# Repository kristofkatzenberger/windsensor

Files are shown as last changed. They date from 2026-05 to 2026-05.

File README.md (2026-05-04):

# Portable Wind Sensor based on MEMS Pressure Sensors

This repository contains the design files for a portable wind sensor developed in 2025/26 at the University of Applied Sciences Technikum Wien. This project was completed as part of the Bachelor's Thesis:

"Entwicklung eines tragbaren Windsensors auf Basis von MEMS-Drucksensoren"
(Development of a Portable Wind Sensor Based on MEMS Pressure Sensors)

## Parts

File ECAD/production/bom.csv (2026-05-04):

Designator | Footprint | Quantity | Value | LCSC Part #
C1, C12, C4, C7, C9 | 0402 | 5 | 10uF
C10 | 0402 | 1 | 47nF
C11, C19, C2, C21, C22, C23, C24, C25, C26, C27, C28, C29, C30, C31, C32, C33, C34, C35, C36, C37, C38, C39, C40, C41, C43, C44, C45, C47, C5, C6 | 0402 | 30 | 100nF
C13 | 0402 | 1 | 4.7uF
C14 | 0402 | 1 | 20uF
C15, C16, C17, C20, C3, C46 | 0402 | 6 | 1uF
C18, C8 | 0402 | 2 | 22uF
C42 | 0402 | 1 | 2.2uF
D1 | 0603 | 1 | LED WHITE
D2 | 0603 | 1 | LED RED
D3, D4 | LESD5D50CT1G | 2 | LESD5D5.0CT1G
IC1 | AP33772SDKZ13FA01 | 1 | AP33772SDKZ-13-FA01
IC2 | SON65P200X200X80-7N | 1 | LP5910-1.8DRVR
IC3 | BMI270 | 1 | BMI270
J1 | USB_C_Receptacle_GCT_USB4105-xx-A_16P_TopMnt_Horizontal | 1 | USB_C_Receptacle_USB2.0_16P
J3 | JST_ZH_B2B-ZR-SM4-TF_1x02-1MP_P1.50mm_Vertical | 1 | Conn_01x02_Pin
J7 | JST_SM13B-GHS-TB | 1 | SM13B-GHS-TB
L1 | L_Murata_DFE201610P | 1 | 470nH
L2 | 1008 | 1 | 1uH
Q1, Q2 | Diodes_PowerDI3333-8 | 2 | DMN3008SFG
R1 | 0402 | 1 | 6,2k
R10, R17, R32, R39, R40, R41, R42, R43, R44, R6, R7 | 0402 | 11 | 10k
R11 | 0402 | 1 | 511k
R12 | 0402 | 1 | 1.5k
R14 | 0402 | 1 | 91k
R15, R16, R22, R23, R24, R25, R26, R27, R28, R29, R30, R31 | 0402 | 12 | 4.7k
R18, R19, R20, R21 | 0402 | 4 | 100k
R2 | 0402 | 1 | 100
R3 | 1206 | 1 | 5m
R33, R34, R35, R36, R37, R38 | 0402 | 6 | 50
R4, R5 | 0402 | 2 | 5.1k
R8 | 0402 | 1 | 30.1k
R9 | 0402 | 1 | 5.23k
TF1 | TF-SMD_TF-012 | 1 | TF-012
TH1 | 0603 | 1 | SDNT1608X103F3950FTF
U1 | WQFN-HR18__RYK_TEX | 1 | BQ25628ERYKR
U10, U11, U12, U4, U5, U6, U7, U8, U9 | LGA8S145X65P2X4_200X250X110-V | 9 | DPS368
U13 | BGA9_BMM350_BOS | 1 | BMM350
U14 | TSSOP-24_4.4x7.8mm_P0.65mm | 1 | TCA9548APWR
U2 | YFF0015AHAN | 1 | TPS63805YFFR
U3 | ESP32-S3-WROOM-1 | 1 | ESP32-S3-WROOM-1

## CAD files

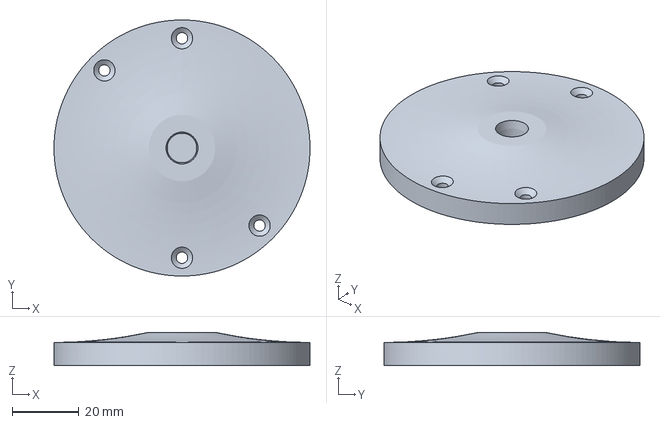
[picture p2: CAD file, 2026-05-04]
MCAD/WindSensor-Tripod-Adapter.3mf
77.0 x 77.0 x 10.0 mm

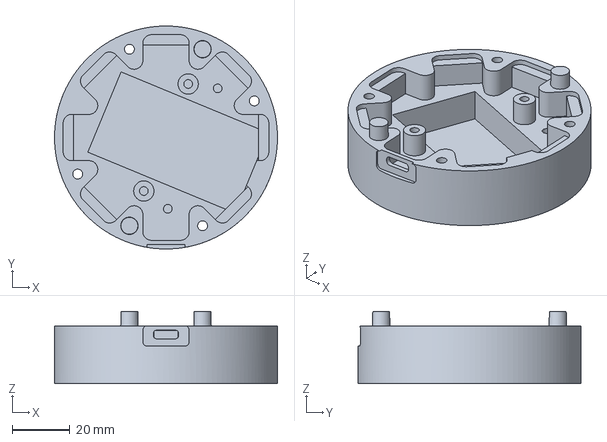
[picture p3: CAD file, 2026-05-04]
MCAD/WindSensor-Bottom.3mf
77.0 x 77.0 x 25.0 mm

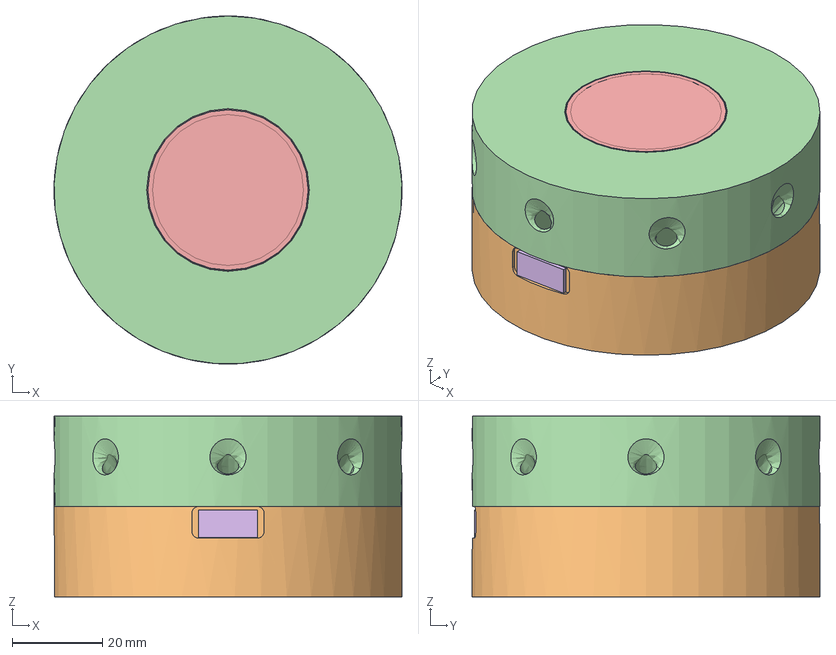
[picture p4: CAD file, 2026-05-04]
MCAD/WindSensor.FCStd
77.0 x 77.0 x 40.0 mm
M3x3.8-Insert018
M3x3.8-Insert017
M3x3.8-Insert016
M3x3.8-Insert
M3x12-Screw027
M2x6-Screw018
M2x6-Screw017
M2x6-Screw016
M2x6-Screw
M3x8-Screw018
M3x8-Screw017
M3x8-Screw016
M3x8-Screw
M3x6-Screw018
M3x6-Screw017
M3x6-Screw016
M3x6-Screw
BatteryHolder
ScreenConnector
1_28INCH-240X240-TFT
1_28INCH-240X240-TFT-TOUCH
1_28INCH_TOUCH_LCD-PCBA
1_28INCH_TOUCH_LCD-PCBA001
STUDS-M2XH2_5
STUDS-M2XH2_006
STUDS-M2XH2_007
STUDS-M2XH2_008
Top
Battery
USB-C-Plug
M3x12-Screw028
M3x12-Screw029
M3x12-Screw030
Bottom
PCB

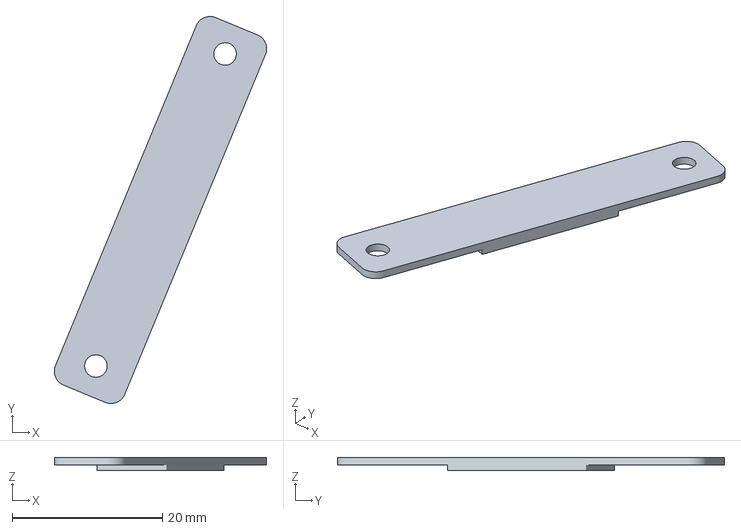
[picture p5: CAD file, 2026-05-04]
MCAD/WindSensor-BatteryHolder.3mf
28.3 x 51.6 x 1.70 mm

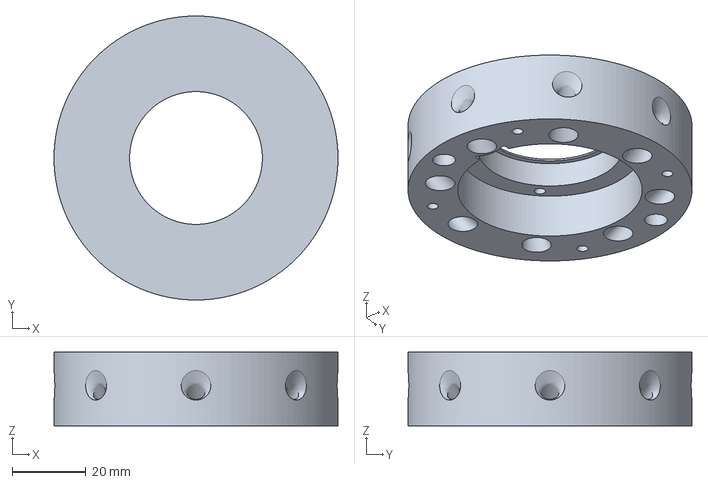
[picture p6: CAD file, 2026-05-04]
MCAD/WindSensor-Top.3mf
77.0 x 77.0 x 20.0 mm

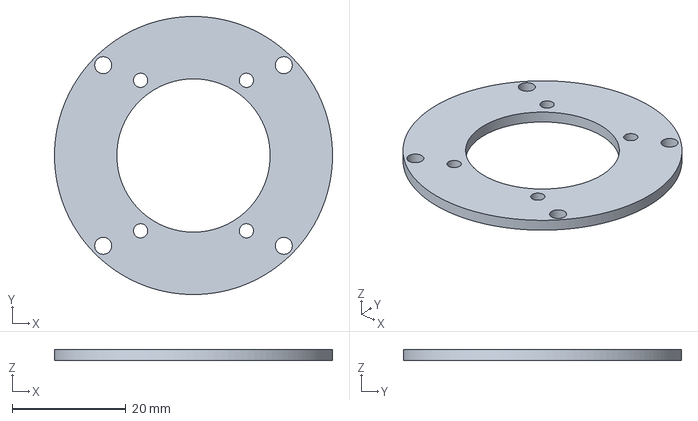
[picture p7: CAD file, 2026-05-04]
MCAD/WindSensor-ScreenConnector.3mf
49.0 x 49.0 x 2.00 mm

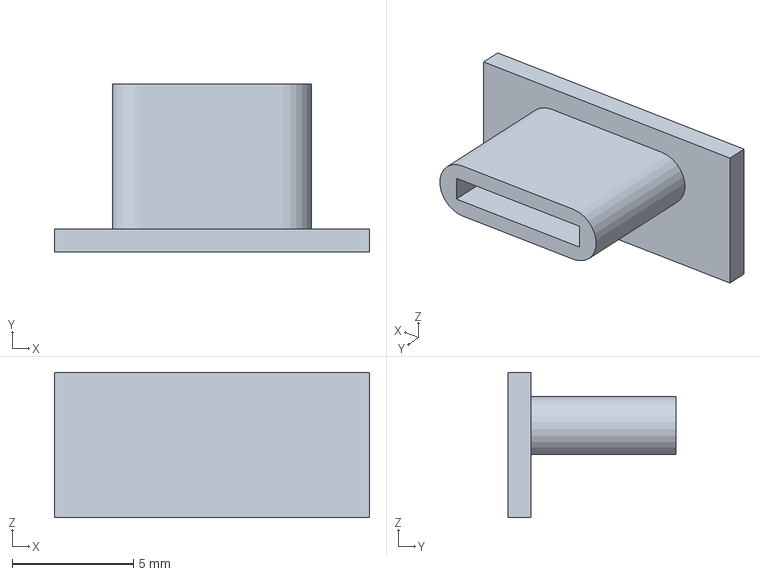
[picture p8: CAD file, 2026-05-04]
MCAD/WindSensor-USB-C-Plug.3mf
13.0 x 6.95 x 6.00 mm

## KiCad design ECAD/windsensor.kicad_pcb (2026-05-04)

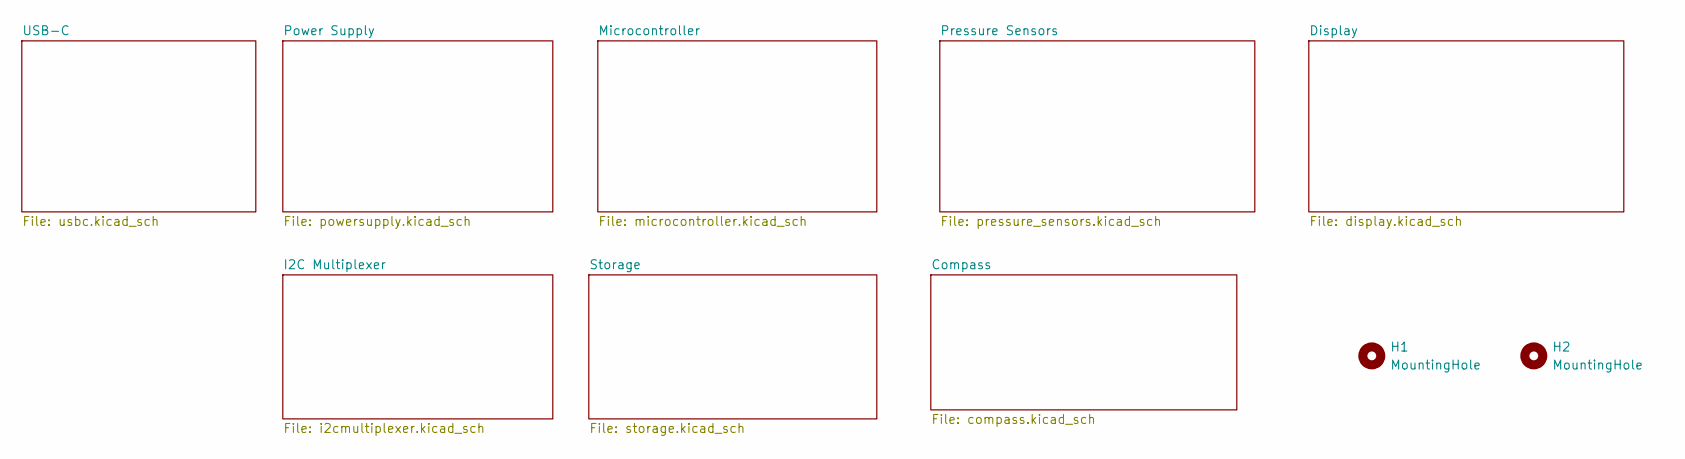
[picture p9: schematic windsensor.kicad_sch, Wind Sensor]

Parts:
H1, H2: MountingHole; MountingHole_3.2mm_M3

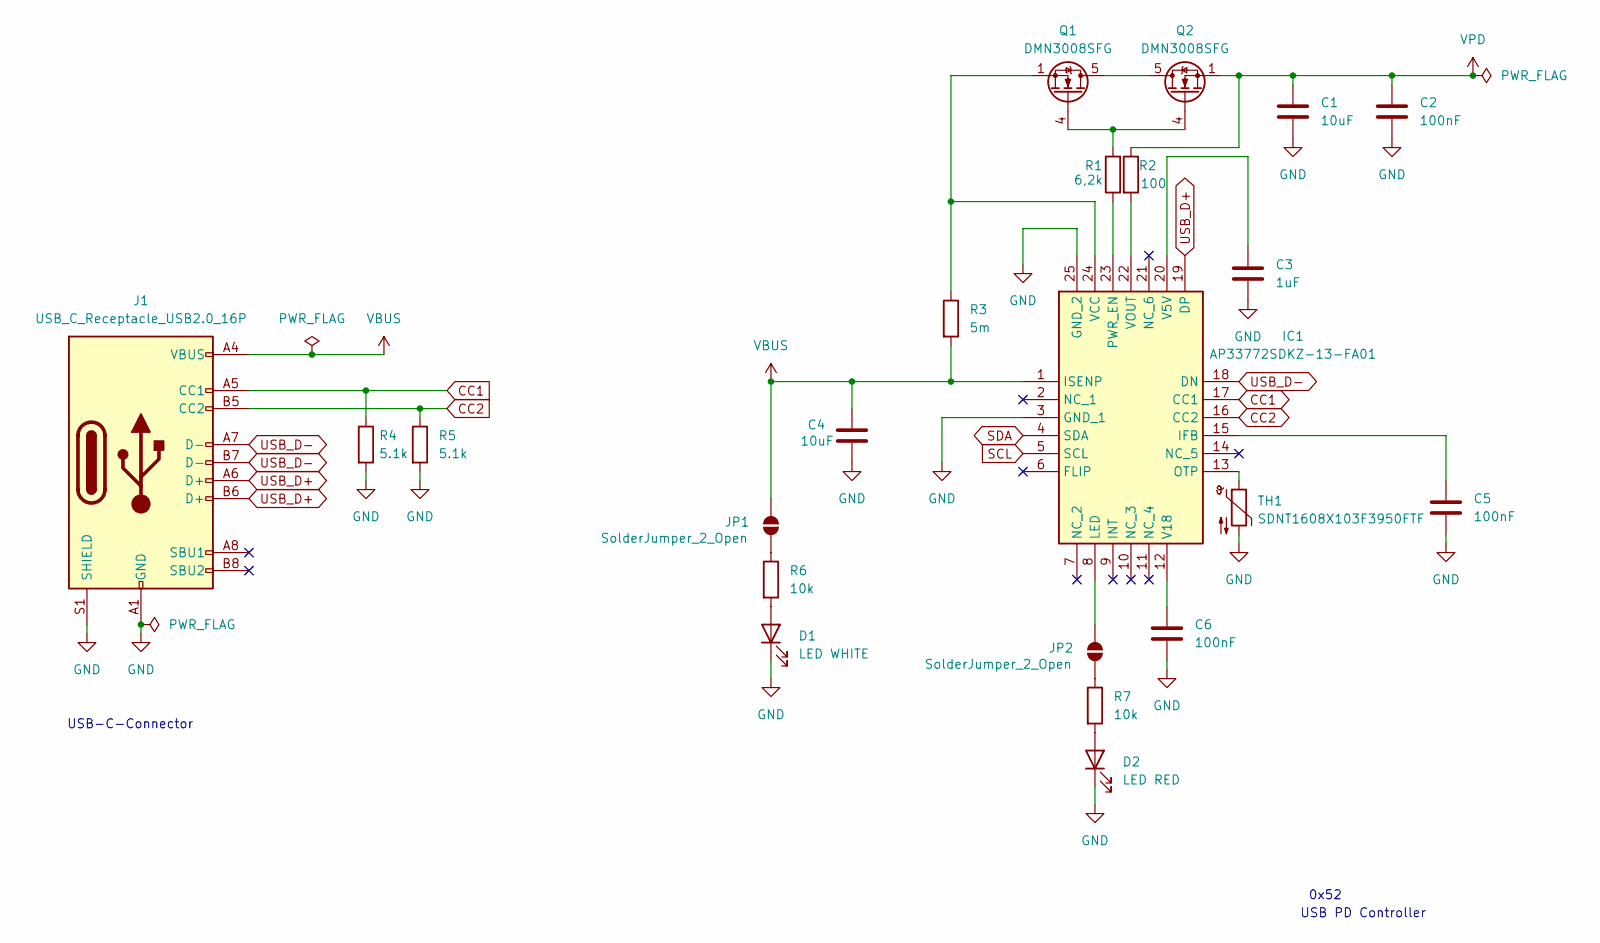
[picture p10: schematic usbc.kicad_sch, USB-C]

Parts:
C1, C4: 10uF; C_0402_1005Metric
C2, C5, C6: 100nF; C_0402_1005Metric
C3: 1uF; C_0402_1005Metric
D1: LED WHITE; LED_0603_1608Metric
D2: LED RED; LED_0603_1608Metric
IC1: AP33772SDKZ-13-FA01; AP33772SDKZ13FA01; Manufacturer_Part_Number AP33772SDKZ-13-FA01; Mouser Part Number 621-P33772SDKZ13FA01
J1: USB_C_Receptacle_USB2.0_16P; USB_C_Receptacle_GCT_USB4105-xx-A_16P_TopMnt_Horizontal
JP1, JP2: SolderJumper_2_Open; SolderJumper-2_P1.3mm_Open_TrianglePad1.0x1.5mm
Q1, Q2: DMN3008SFG; Diodes_PowerDI3333-8
R1: 6,2k; R_0402_1005Metric
R2: 100; R_0402_1005Metric
R3: 5m; R_1206_3216Metric; Tolerance 1%
R4, R5: 5.1k; R_0402_1005Metric
R6, R7: 10k; R_0402_1005Metric
TH1: SDNT1608X103F3950FTF; R_0603_1608Metric

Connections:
CC1: IC1.17 (CC1), J1.A5 (CC1), R4.1
CC2: IC1.16 (CC2), J1.B5 (CC2), R5.1
GND: C1.2, C2.2, C3.2, C4.2, C5.2, C6.2, D1.1 (K), D2.1 (K), IC1.3 (GND_1), IC1.25 (GND_2), J1.A1 (GND), J1.A12 (GND), J1.B1 (GND), J1.B12 (GND), J1.S1 (SHIELD), R4.2, R5.2, TH1.2; also elsewhere on the board
unnamed: D1.2 (A), R6.2
unnamed: D2.2 (A), R7.2
unnamed: C5.1, IC1.15 (IFB)
unnamed: IC1.8 (LED), JP2.1 (A)
unnamed: IC1.13 (OTP), TH1.1
unnamed: IC1.23 (PWR_EN), R1.1
unnamed: C3.1, IC1.20 (V5V)
unnamed: C6.1, IC1.12 (V18)
unnamed: IC1.24 (VCC), Q1.1 (S), Q1.2 (S), Q1.3 (S), R3.1
unnamed: IC1.22 (VOUT), R2.2
unnamed: JP1.2 (B), R6.1
unnamed: JP2.2 (B), R7.1
unnamed: Q1.5 (D), Q2.5 (D)
unnamed: Q1.4 (G), Q2.4 (G), R1.2
SCL: IC1.5 (SCL); also elsewhere on the board
SDA: IC1.4 (SDA); also elsewhere on the board
USB_D+: IC1.19 (DP), J1.A6 (D+), J1.B6 (D+); also elsewhere on the board
USB_D-: IC1.18 (DN), J1.A7 (D-), J1.B7 (D-); also elsewhere on the board
VBUS: C4.1, IC1.1 (ISENP), J1.A4 (VBUS), J1.A9 (VBUS), J1.B4 (VBUS), J1.B9 (VBUS), JP1.1 (A), R3.2
VPD: C1.1, C2.1, Q2.1 (S), Q2.2 (S), Q2.3 (S), R2.1; also elsewhere on the board

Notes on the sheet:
USB PD Controller
USB-C-Connector
0x52

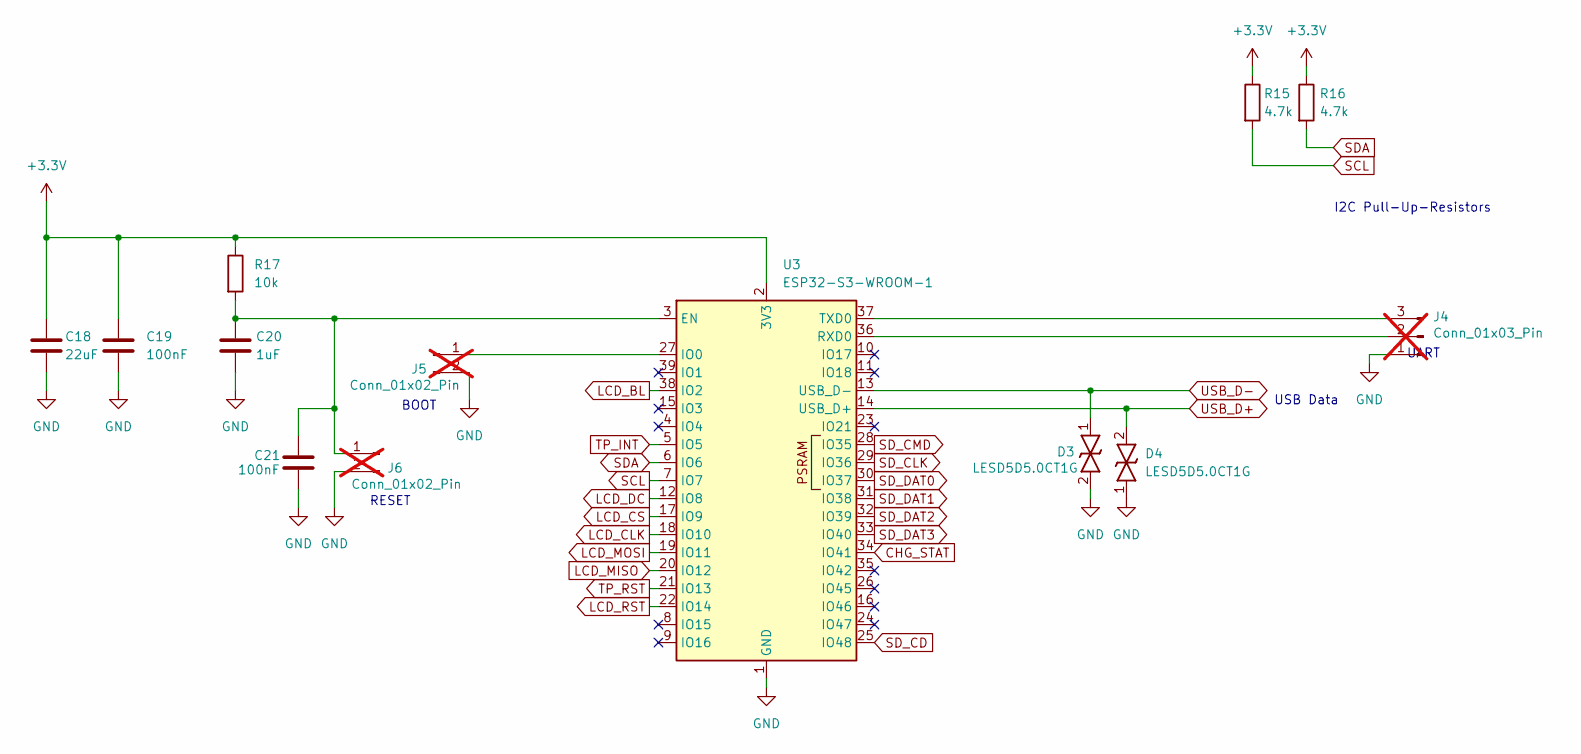
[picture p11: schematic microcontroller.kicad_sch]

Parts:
C18: 22uF; C_0402_1005Metric
C19, C21: 100nF; C_0402_1005Metric
C20: 1uF; C_0402_1005Metric
D3, D4: LESD5D5.0CT1G; LESD5D50CT1G; Manufacturer_Part_Number LESD5D5.0CT1G
J4: Conn_01x03_Pin; PinHeader_1x03_P2.54mm_Vertical; not fitted
J5, J6: Conn_01x02_Pin; PinHeader_1x02_P2.54mm_Vertical; not fitted
R15, R16: 4.7k; R_0402_1005Metric
R17: 10k; R_0402_1005Metric
U3: ESP32-S3-WROOM-1

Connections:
+3.3V: C18.1, C19.1, R15.1, R16.1, R17.1, U3.2 (3V3); also elsewhere on the board
CHG_STAT: U3.34 (IO41); also elsewhere on the board
GND: C18.2, C19.2, C20.2, C21.2, D3.2, D4.1, J4.1, J5.2, J6.2, U3.1 (GND), U3.40 (GND), U3.41 (GND); also elsewhere on the board
LCD_BL: U3.38 (IO2); also elsewhere on the board
LCD_CLK: U3.18 (IO10); also elsewhere on the board
LCD_CS: U3.17 (IO9); also elsewhere on the board
LCD_DC: U3.12 (IO8); also elsewhere on the board
LCD_MISO: U3.20 (IO12); also elsewhere on the board
LCD_MOSI: U3.19 (IO11); also elsewhere on the board
LCD_RST: U3.22 (IO14); also elsewhere on the board
unnamed: J4.2, U3.36 (RXD0)
unnamed: J4.3, U3.37 (TXD0)
unnamed: J5.1, U3.27 (IO0)
unnamed: C20.1, C21.1, J6.1, R17.2, U3.3 (EN)
SCL: R15.2, U3.7 (IO7); also elsewhere on the board
SDA: R16.2, U3.6 (IO6); also elsewhere on the board
SD_CD: U3.25 (IO48); also elsewhere on the board
SD_CLK: U3.29 (IO36); also elsewhere on the board
SD_CMD: U3.28 (IO35); also elsewhere on the board
SD_DAT0: U3.30 (IO37); also elsewhere on the board
SD_DAT1: U3.31 (IO38); also elsewhere on the board
SD_DAT2: U3.32 (IO39); also elsewhere on the board
SD_DAT3: U3.33 (IO40); also elsewhere on the board
TP_INT: U3.5 (IO5); also elsewhere on the board
TP_RST: U3.21 (IO13); also elsewhere on the board
USB_D+: D4.2, U3.14 (USB_D+); also elsewhere on the board
USB_D-: D3.1, U3.13 (USB_D-); also elsewhere on the board

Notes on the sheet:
I2C Pull-Up-Resistors
UART
USB Data
BOOT
RESET

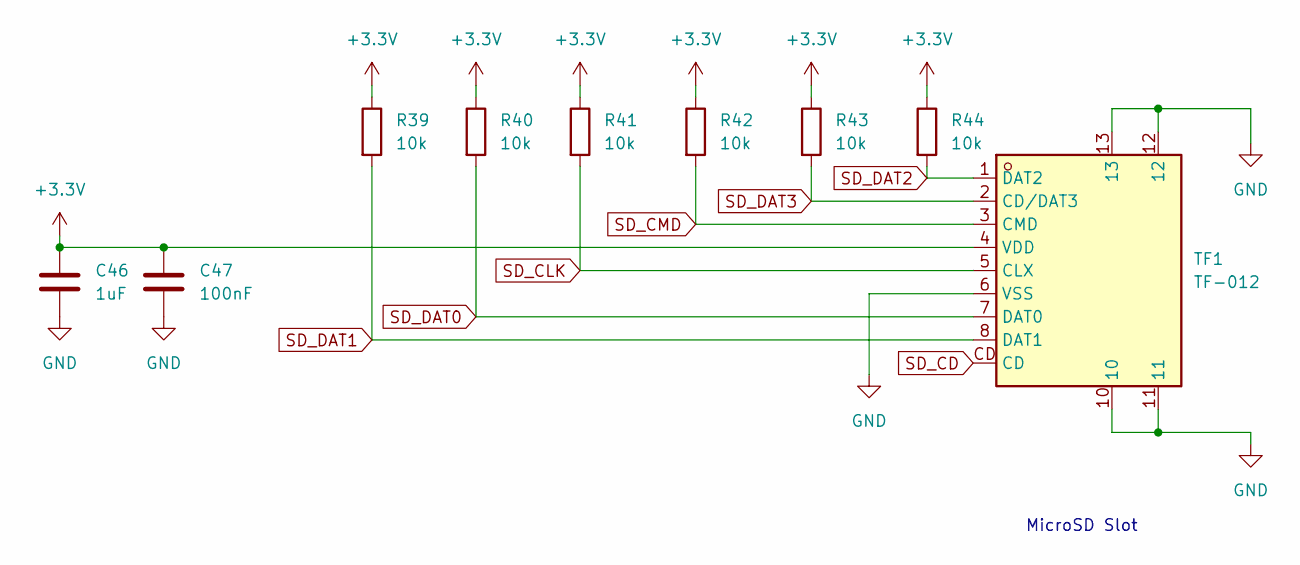
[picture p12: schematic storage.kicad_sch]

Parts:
C46: 1uF; C_0402_1005Metric
C47: 100nF; C_0402_1005Metric
R39, R40, R41, R42, R43, R44: 10k; R_0402_1005Metric
TF1: TF-012; TF-SMD_TF-012; Manufacturer Part TF-012; LCSC Part Name 自弹式 MicroSD卡(TF卡) 卡座

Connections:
+3.3V: C46.1, C47.1, R39.1, R40.1, R41.1, R42.1, R43.1, R44.1, TF1.4 (VDD); also elsewhere on the board
GND: C46.2, C47.2, TF1.6 (VSS), TF1.10, TF1.11, TF1.12, TF1.13; also elsewhere on the board
SD_CD: TF1.CD; also elsewhere on the board
SD_CLK: R41.2, TF1.5 (CLX); also elsewhere on the board
SD_CMD: R42.2, TF1.3 (CMD); also elsewhere on the board
SD_DAT0: R40.2, TF1.7 (DAT0); also elsewhere on the board
SD_DAT1: R39.2, TF1.8 (DAT1); also elsewhere on the board
SD_DAT2: R44.2, TF1.1 (DAT2); also elsewhere on the board
SD_DAT3: R43.2, TF1.2 (CD/DAT3); also elsewhere on the board

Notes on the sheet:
MicroSD Slot

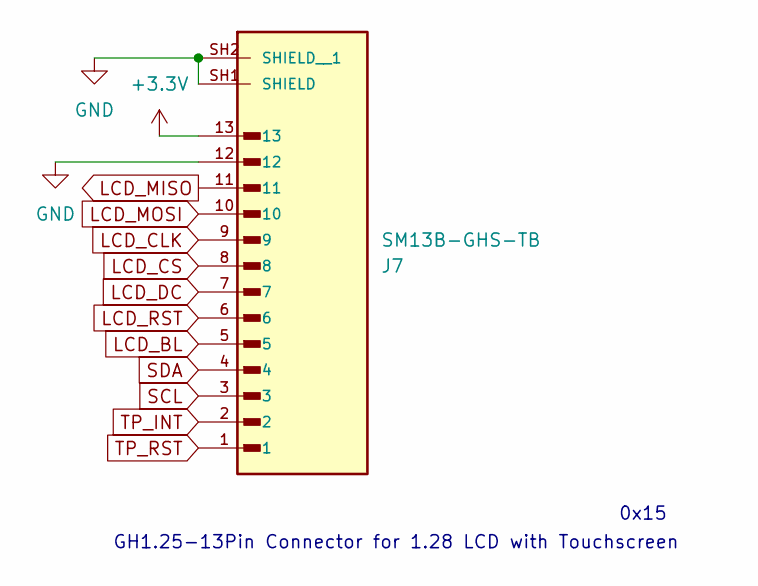
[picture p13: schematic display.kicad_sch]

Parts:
J7: SM13B-GHS-TB; JST_SM13B-GHS-TB; PARTREV 18/3/21

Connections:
+3.3V: J7.13; also elsewhere on the board
GND: J7.12, J7.SH1 (SHIELD), J7.SH2 (SHIELD__1); also elsewhere on the board
LCD_BL: J7.5; also elsewhere on the board
LCD_CLK: J7.9; also elsewhere on the board
LCD_CS: J7.8; also elsewhere on the board
LCD_DC: J7.7; also elsewhere on the board
LCD_MISO: J7.11; also elsewhere on the board
LCD_MOSI: J7.10; also elsewhere on the board
LCD_RST: J7.6; also elsewhere on the board
SCL: J7.3; also elsewhere on the board
SDA: J7.4; also elsewhere on the board
TP_INT: J7.2; also elsewhere on the board
TP_RST: J7.1; also elsewhere on the board

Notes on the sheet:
GH1.25-13Pin Connector for 1.28 LCD with Touchscreen
0x15

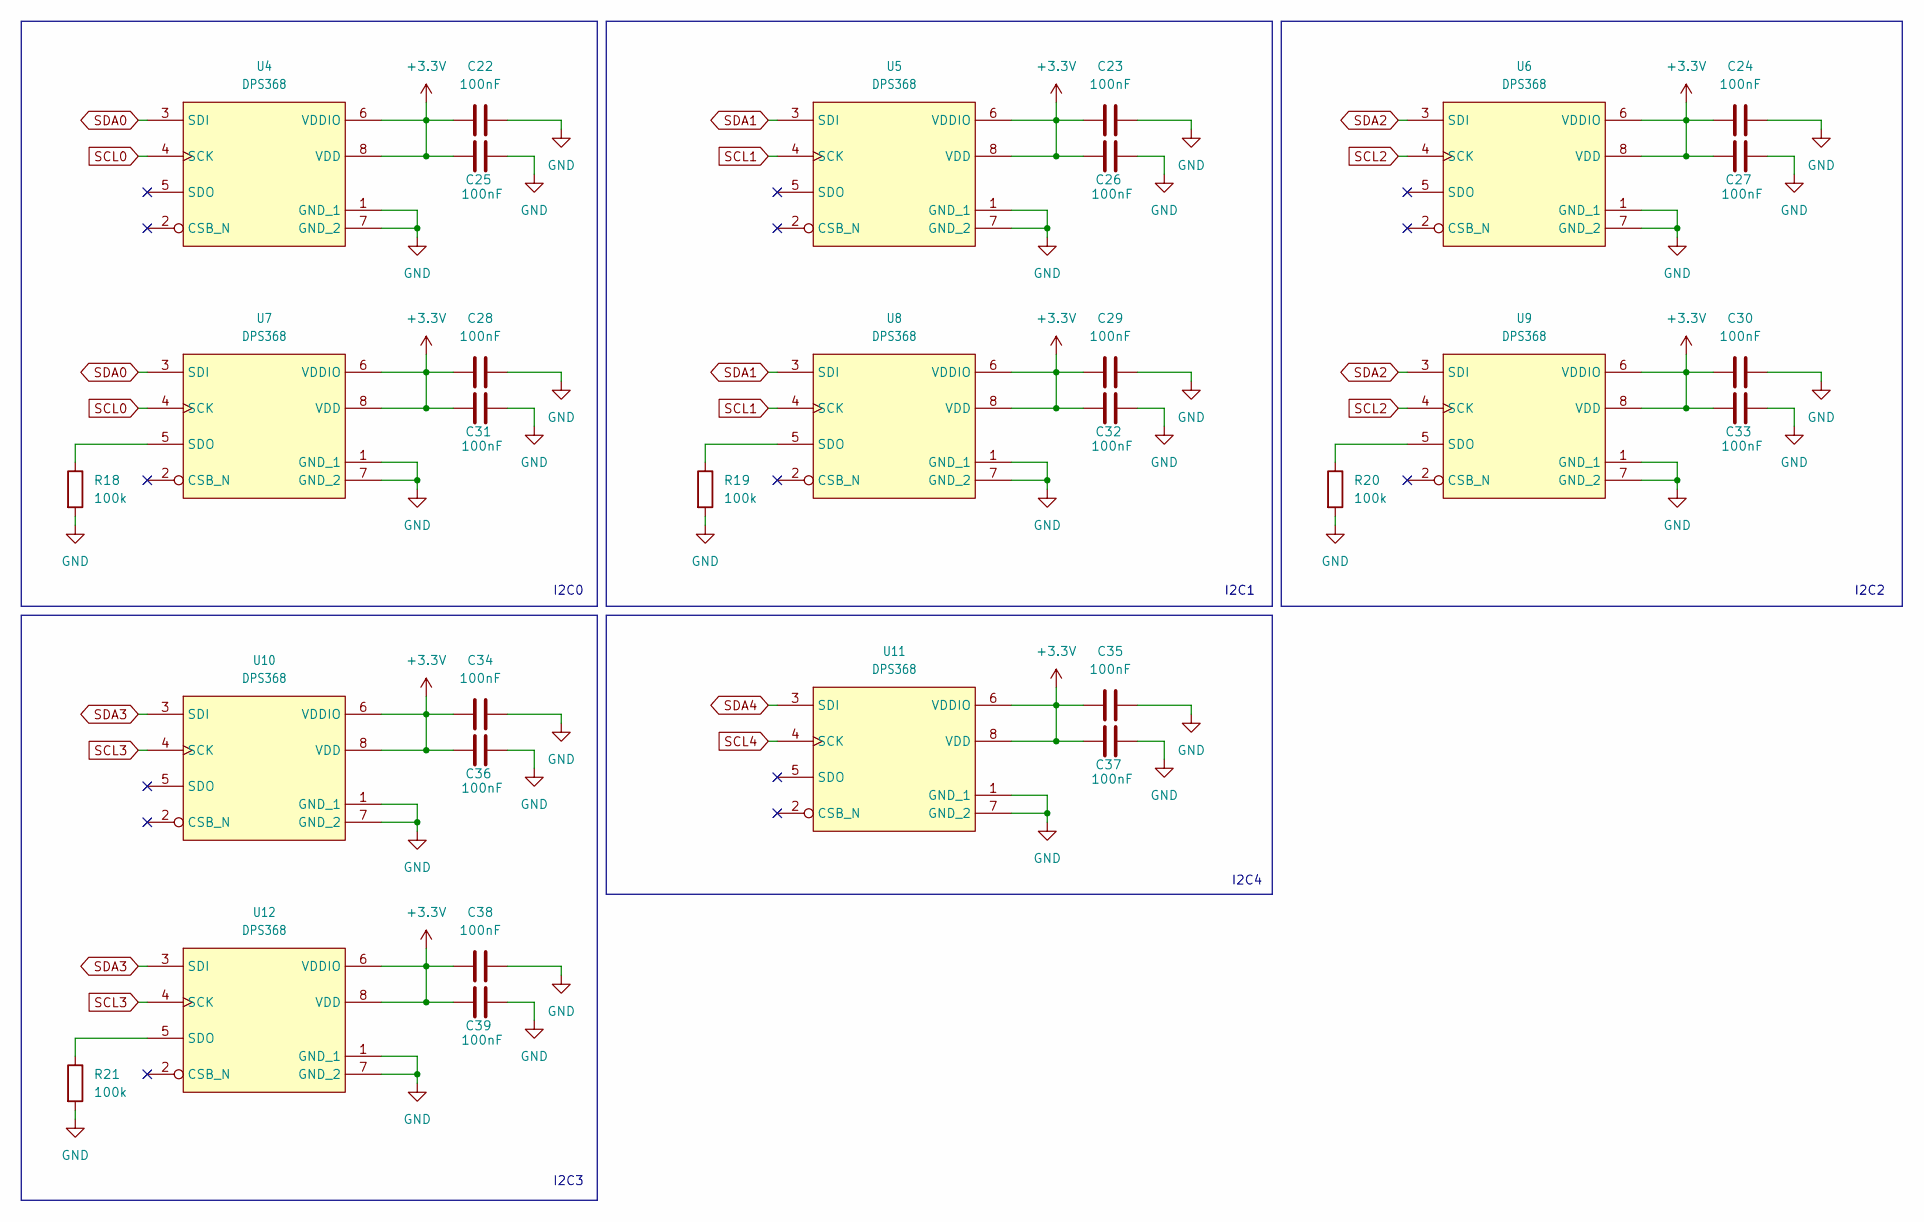
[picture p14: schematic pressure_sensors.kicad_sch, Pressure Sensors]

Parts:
C22, C23, C24, C25, C26, C27, C28, C29, C30, C31, C32, C33, C34, C35, C36, C37, C38, C39: 100nF; C_0402_1005Metric
R18, R19, R20, R21: 100k; R_0402_1005Metric
U4, U5, U6, U7, U8, U9, U10, U11, U12: DPS368; LGA8S145X65P2X4_200X250X110-V

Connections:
+3.3V: C22.1, C23.1, C24.1, C25.1, C26.1, C27.1, C28.1, C29.1, C30.1, C31.1, C32.1, C33.1, C34.1, C35.1, C36.1, C37.1, C38.1, C39.1, U4.6 (VDDIO), U4.8 (VDD), U5.6 (VDDIO), U5.8 (VDD), U6.6 (VDDIO), U6.8 (VDD), U7.6 (VDDIO), U7.8 (VDD), U8.6 (VDDIO), U8.8 (VDD), U9.6 (VDDIO), U9.8 (VDD), U10.6 (VDDIO), U10.8 (VDD), U11.6 (VDDIO), U11.8 (VDD), U12.6 (VDDIO), U12.8 (VDD); also elsewhere on the board
GND: C22.2, C23.2, C24.2, C25.2, C26.2, C27.2, C28.2, C29.2, C30.2, C31.2, C32.2, C33.2, C34.2, C35.2, C36.2, C37.2, C38.2, C39.2, R18.2, R19.2, R20.2, R21.2, U4.1 (GND_1), U4.7 (GND_2), U5.1 (GND_1), U5.7 (GND_2), U6.1 (GND_1), U6.7 (GND_2), U7.1 (GND_1), U7.7 (GND_2), U8.1 (GND_1), U8.7 (GND_2), U9.1 (GND_1), U9.7 (GND_2), U10.1 (GND_1), U10.7 (GND_2), U11.1 (GND_1), U11.7 (GND_2), U12.1 (GND_1), U12.7 (GND_2); also elsewhere on the board
unnamed: R18.1, U7.5 (SDO)
unnamed: R19.1, U8.5 (SDO)
unnamed: R20.1, U9.5 (SDO)
unnamed: R21.1, U12.5 (SDO)
SCL0: U4.4 (SCK), U7.4 (SCK); also elsewhere on the board
SCL1: U5.4 (SCK), U8.4 (SCK); also elsewhere on the board
SCL2: U6.4 (SCK), U9.4 (SCK); also elsewhere on the board
SCL3: U10.4 (SCK), U12.4 (SCK); also elsewhere on the board
SCL4: U11.4 (SCK); also elsewhere on the board
SDA0: U4.3 (SDI), U7.3 (SDI); also elsewhere on the board
SDA1: U5.3 (SDI), U8.3 (SDI); also elsewhere on the board
SDA2: U6.3 (SDI), U9.3 (SDI); also elsewhere on the board
SDA3: U10.3 (SDI), U12.3 (SDI); also elsewhere on the board
SDA4: U11.3 (SDI); also elsewhere on the board

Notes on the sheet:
I2C3
I2C2
I2C4
I2C1
I2C0

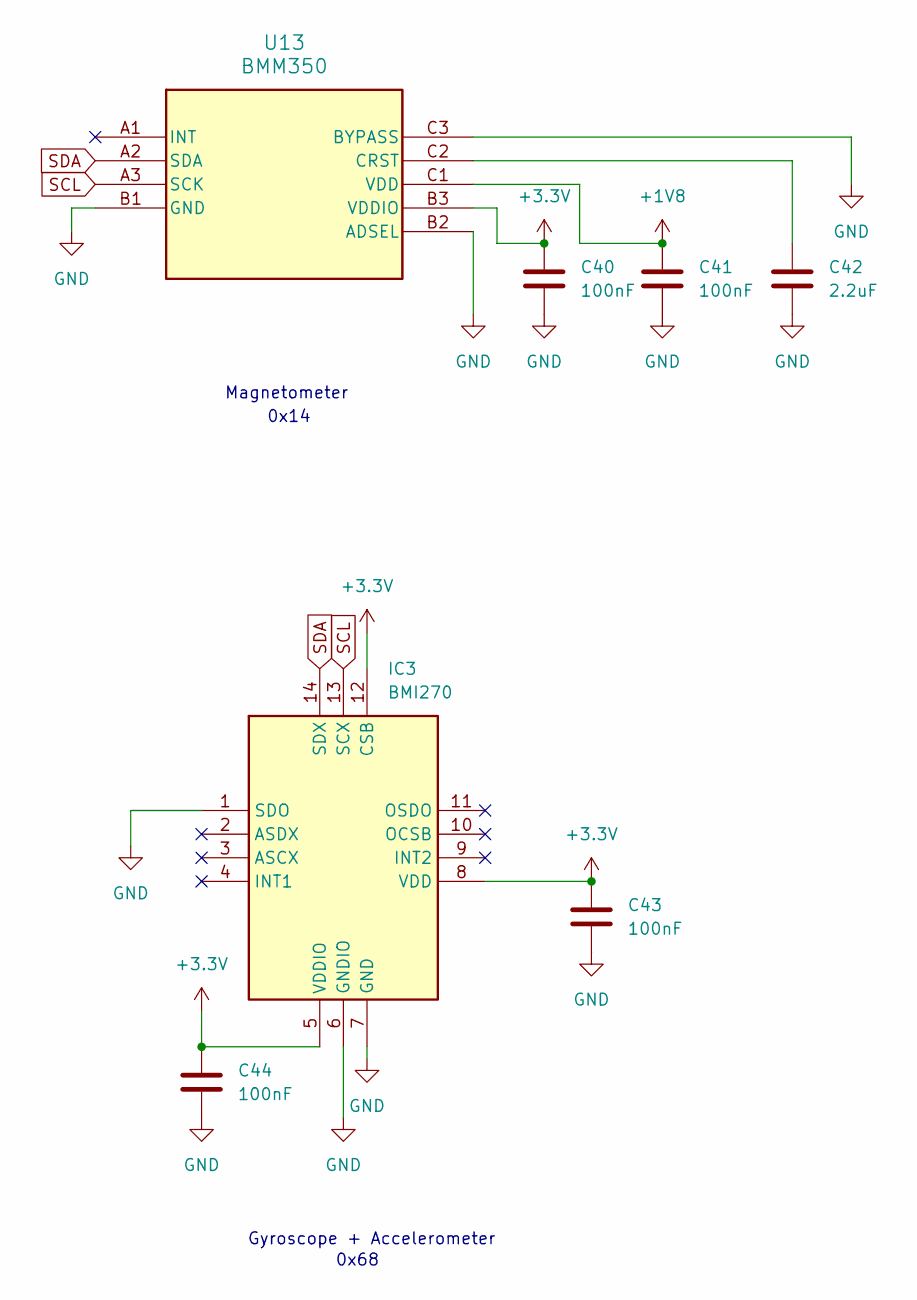
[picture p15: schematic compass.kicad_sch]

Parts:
C40, C41, C43: 100nF; C_0402_1005Metric
C42: 2.2uF; C_0402_1005Metric
C44: 100nF; C_0402_1005Metric_Pad0.74x0.62mm_HandSolder
IC3: BMI270; Mouser Part Number 262-BMI270
U13: BMM350; BGA9_BMM350_BOS

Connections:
+1V8: C41.1, U13.C1 (VDD); also elsewhere on the board
+3.3V: C40.1, C43.1, C44.1, IC3.5 (VDDIO), IC3.8 (VDD), IC3.12 (CSB), U13.B3 (VDDIO); also elsewhere on the board
GND: C40.2, C41.2, C42.1, C43.2, C44.2, IC3.1 (SDO), IC3.6 (GNDIO), IC3.7 (GND), U13.B1 (GND), U13.B2 (ADSEL), U13.C3 (BYPASS); also elsewhere on the board
unnamed: C42.2, U13.C2 (CRST)
SCL: IC3.13 (SCX), U13.A3 (SCK); also elsewhere on the board
SDA: IC3.14 (SDX), U13.A2 (SDA); also elsewhere on the board

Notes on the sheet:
Gyroscope + Accelerometer
Magnetometer
0x14
0x68

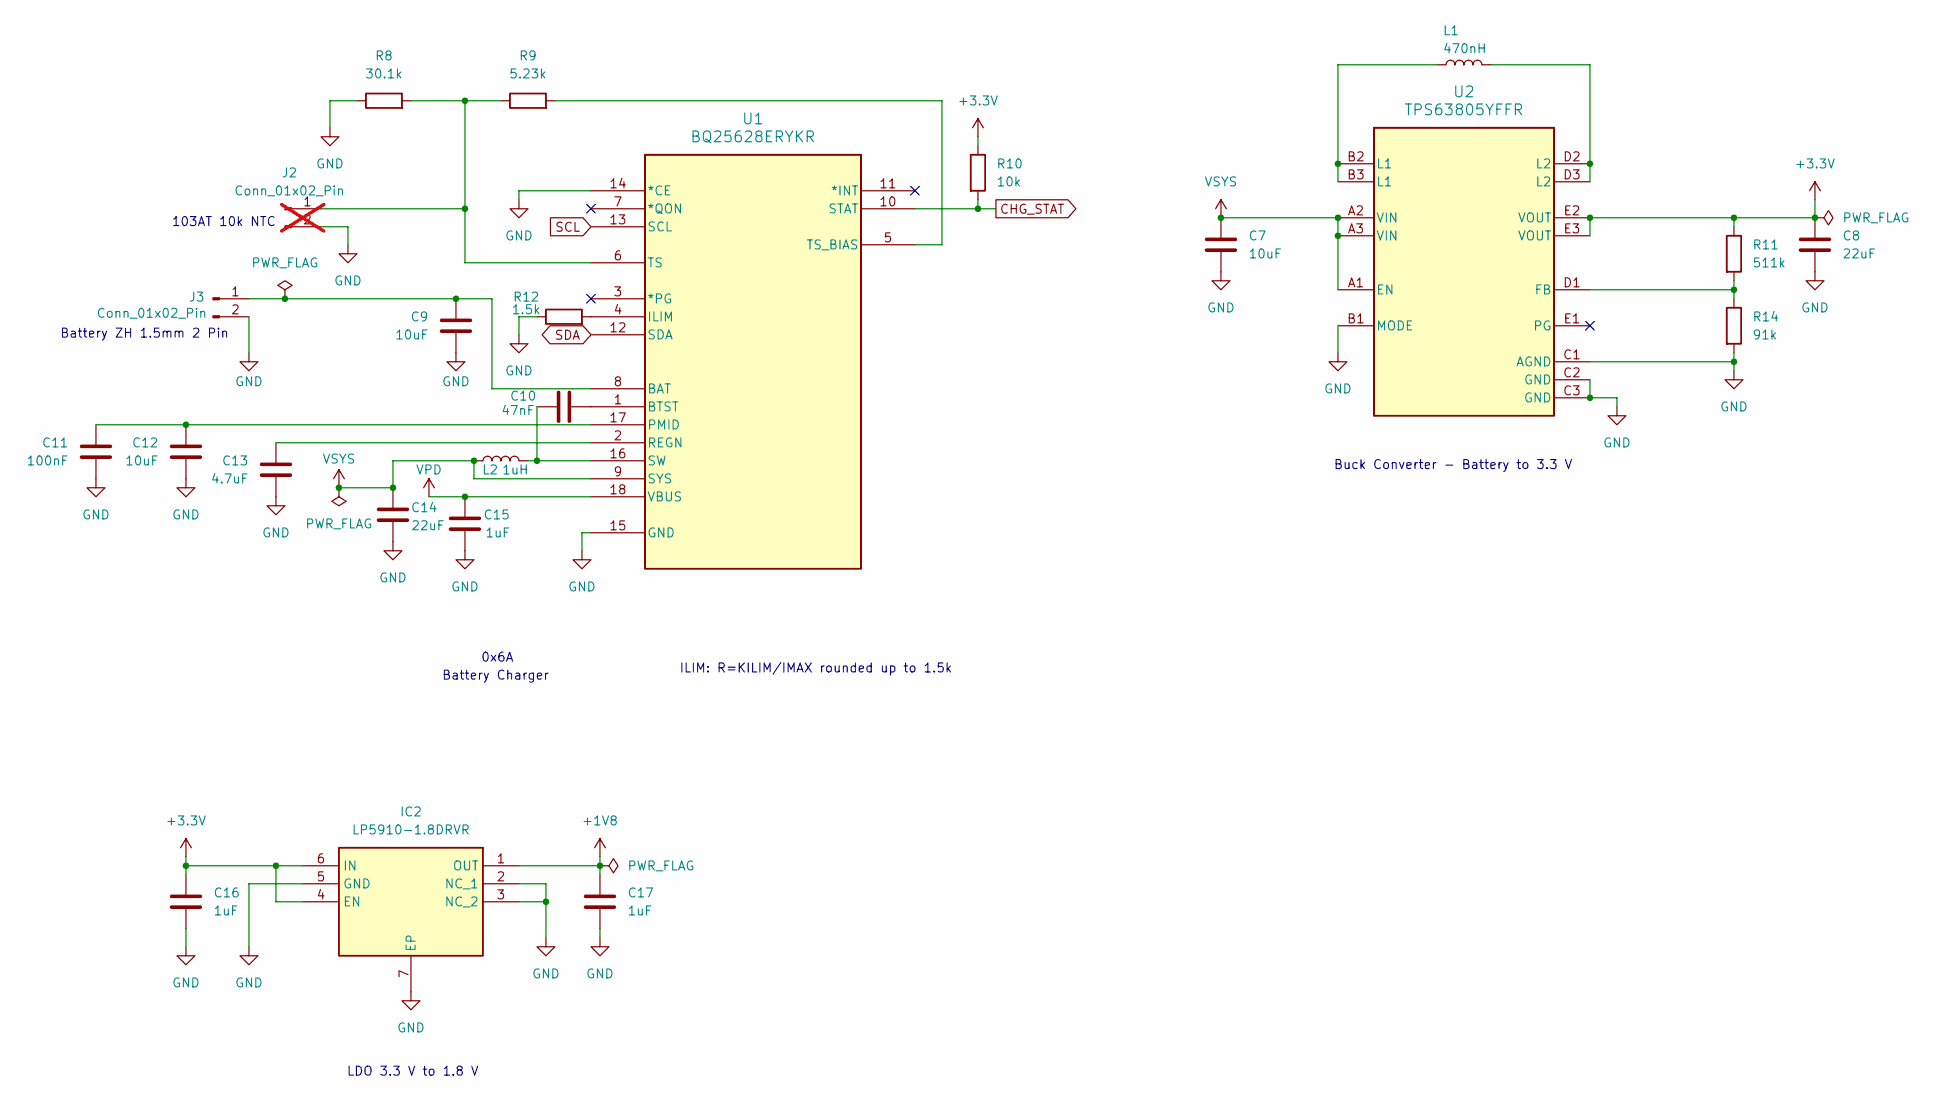
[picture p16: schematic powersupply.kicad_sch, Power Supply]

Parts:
C7, C9, C12: 10uF; C_0402_1005Metric
C8, C14: 22uF; C_0402_1005Metric
C10: 47nF; C_0402_1005Metric
C11: 100nF; C_0402_1005Metric
C13: 4.7uF; C_0402_1005Metric
C15, C16, C17: 1uF; C_0402_1005Metric
IC2: LP5910-1.8DRVR; SON65P200X200X80-7N; Mouser Part Number 595-LP5910-1.8DRVR
J2: Conn_01x02_Pin; PinHeader_1x02_P2.54mm_Vertical; not fitted
J3: Conn_01x02_Pin; JST_ZH_B2B-ZR-SM4-TF_1x02-1MP_P1.50mm_Vertical
L1: 470nH; L_Murata_DFE201610P
L2: 1uH; L_1008_2520Metric
R8: 30.1k; R_0402_1005Metric
R9: 5.23k; R_0402_1005Metric
R10: 10k; R_0402_1005Metric
R11: 511k; R_0402_1005Metric
R12: 1.5k; R_0402_1005Metric
R14: 91k; R_0402_1005Metric
U1: BQ25628ERYKR; WQFN-HR18__RYK_TEX
U2: TPS63805YFFR; YFF0015AHAN

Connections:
+1V8: C17.1, IC2.1 (OUT); also elsewhere on the board
+3.3V: C8.1, C16.1, IC2.4 (EN), IC2.6 (IN), R10.1, R11.1, U2.E2 (VOUT), U2.E3 (VOUT); also elsewhere on the board
CHG_STAT: R10.2, U1.10 (STAT); also elsewhere on the board
GND: C7.2, C8.2, C9.1, C11.1, C12.1, C13.1, C14.1, C15.1, C16.2, C17.2, IC2.2 (NC_1), IC2.3 (NC_2), IC2.5 (GND), IC2.7 (EP), J2.2, J3.2, R8.1, R12.1, R14.2, U1.14 (*CE), U1.15 (GND), U2.B1 (MODE), U2.C1 (AGND), U2.C2 (GND), U2.C3 (GND); also elsewhere on the board
unnamed: J2.1, R8.2, R9.1, U1.6 (TS)
unnamed: C9.2, J3.1, U1.8 (BAT)
unnamed: L1.1, U2.D2 (L2), U2.D3 (L2)
unnamed: L1.2, U2.B2 (L1), U2.B3 (L1)
unnamed: C10.1, U1.1 (BTST)
unnamed: R12.2, U1.4 (ILIM)
unnamed: C11.2, C12.2, U1.17 (PMID)
unnamed: C13.2, U1.2 (REGN)
unnamed: C10.2, L2.2, U1.16 (SW)
unnamed: R9.2, U1.5 (TS_BIAS)
unnamed: R11.2, R14.1, U2.D1 (FB)
SCL: U1.13 (SCL); also elsewhere on the board
SDA: U1.12 (SDA); also elsewhere on the board
VPD: C15.2, U1.18 (VBUS); also elsewhere on the board
VSYS: C7.1, C14.2, L2.1, U1.9 (SYS), U2.A1 (EN), U2.A2 (VIN), U2.A3 (VIN)

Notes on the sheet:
Battery Charger
Battery ZH 1.5mm 2 Pin
ILIM: R=KILIM/IMAX rounded up to 1.5k
103AT 10k NTC
0x6A
LDO 3.3 V to 1.8 V
Buck Converter - Battery to 3.3 V

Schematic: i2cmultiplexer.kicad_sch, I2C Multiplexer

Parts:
C45: 100nF; C_0402_1005Metric
R22, R23, R24, R25, R26, R27, R28, R29, R30, R31: 4.7k; R_0402_1005Metric
R32: 10k; R_0402_1005Metric
R33, R34, R35, R36, R37, R38: 50; R_0402_1005Metric
U14: TCA9548APWR; TSSOP-24_4.4x7.8mm_P0.65mm

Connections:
+3.3V: C45.2, R22.1, R23.1, R24.1, R25.1, R26.1, R27.1, R28.1, R29.1, R30.1, R31.1, R32.1, U14.24 (VCC); also elsewhere on the board
GND: C45.1, R33.2, R34.2, R35.2, R36.2, R37.2, R38.2, U14.1 (A0), U14.2 (A1), U14.12 (GND), U14.21 (A2); also elsewhere on the board
unnamed: R38.1, U14.16 (SC5)
unnamed: R36.1, U14.18 (SC6)
unnamed: R34.1, U14.20 (SC7)
unnamed: R37.1, U14.15 (SD5)
unnamed: R35.1, U14.17 (SD6)
unnamed: R33.1, U14.19 (SD7)
unnamed: R32.2, U14.3 (~RESET)
SCL: U14.22 (SCL); also elsewhere on the board
SCL0: R22.2, U14.5 (SC0); also elsewhere on the board
SCL1: R24.2, U14.7 (SC1); also elsewhere on the board
SCL2: R26.2, U14.9 (SC2); also elsewhere on the board
SCL3: R28.2, U14.11 (SC3); also elsewhere on the board
SCL4: R30.2, U14.14 (SC4); also elsewhere on the board
SDA: U14.23 (SDA); also elsewhere on the board
SDA0: R23.2, U14.4 (SD0); also elsewhere on the board
SDA1: R25.2, U14.6 (SD1); also elsewhere on the board
SDA2: R27.2, U14.8 (SD2); also elsewhere on the board
SDA3: R29.2, U14.10 (SD3); also elsewhere on the board
SDA4: R31.2, U14.13 (SD4); also elsewhere on the board

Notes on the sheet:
0x70

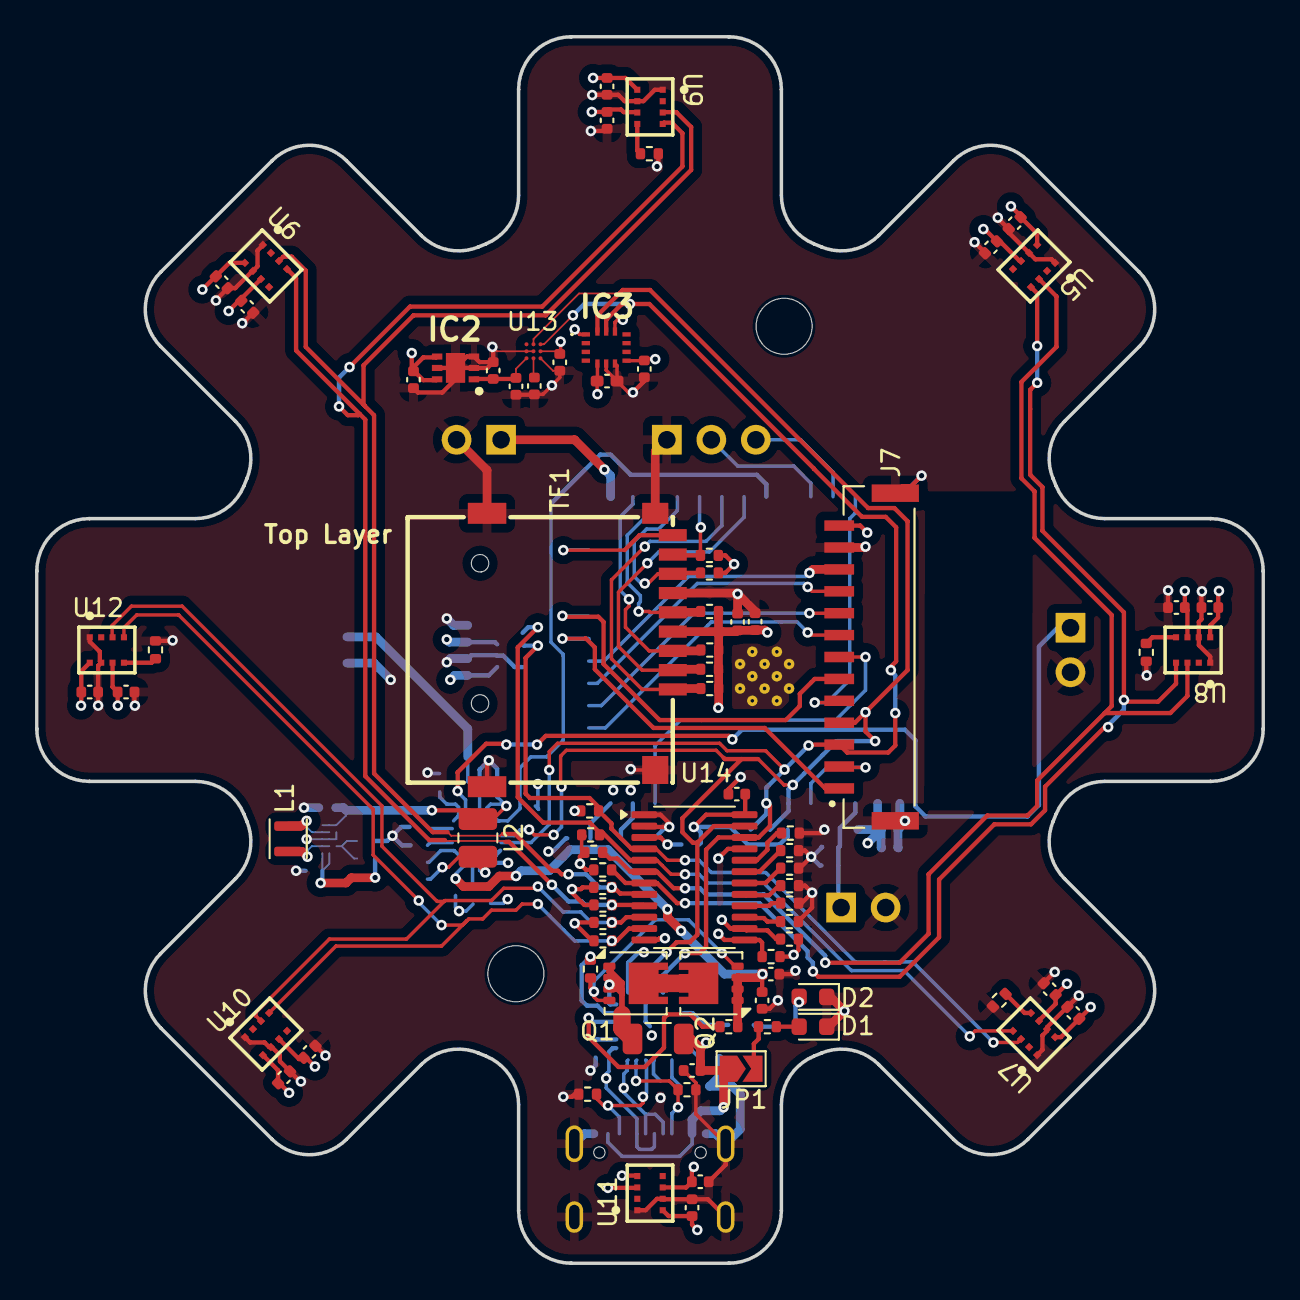
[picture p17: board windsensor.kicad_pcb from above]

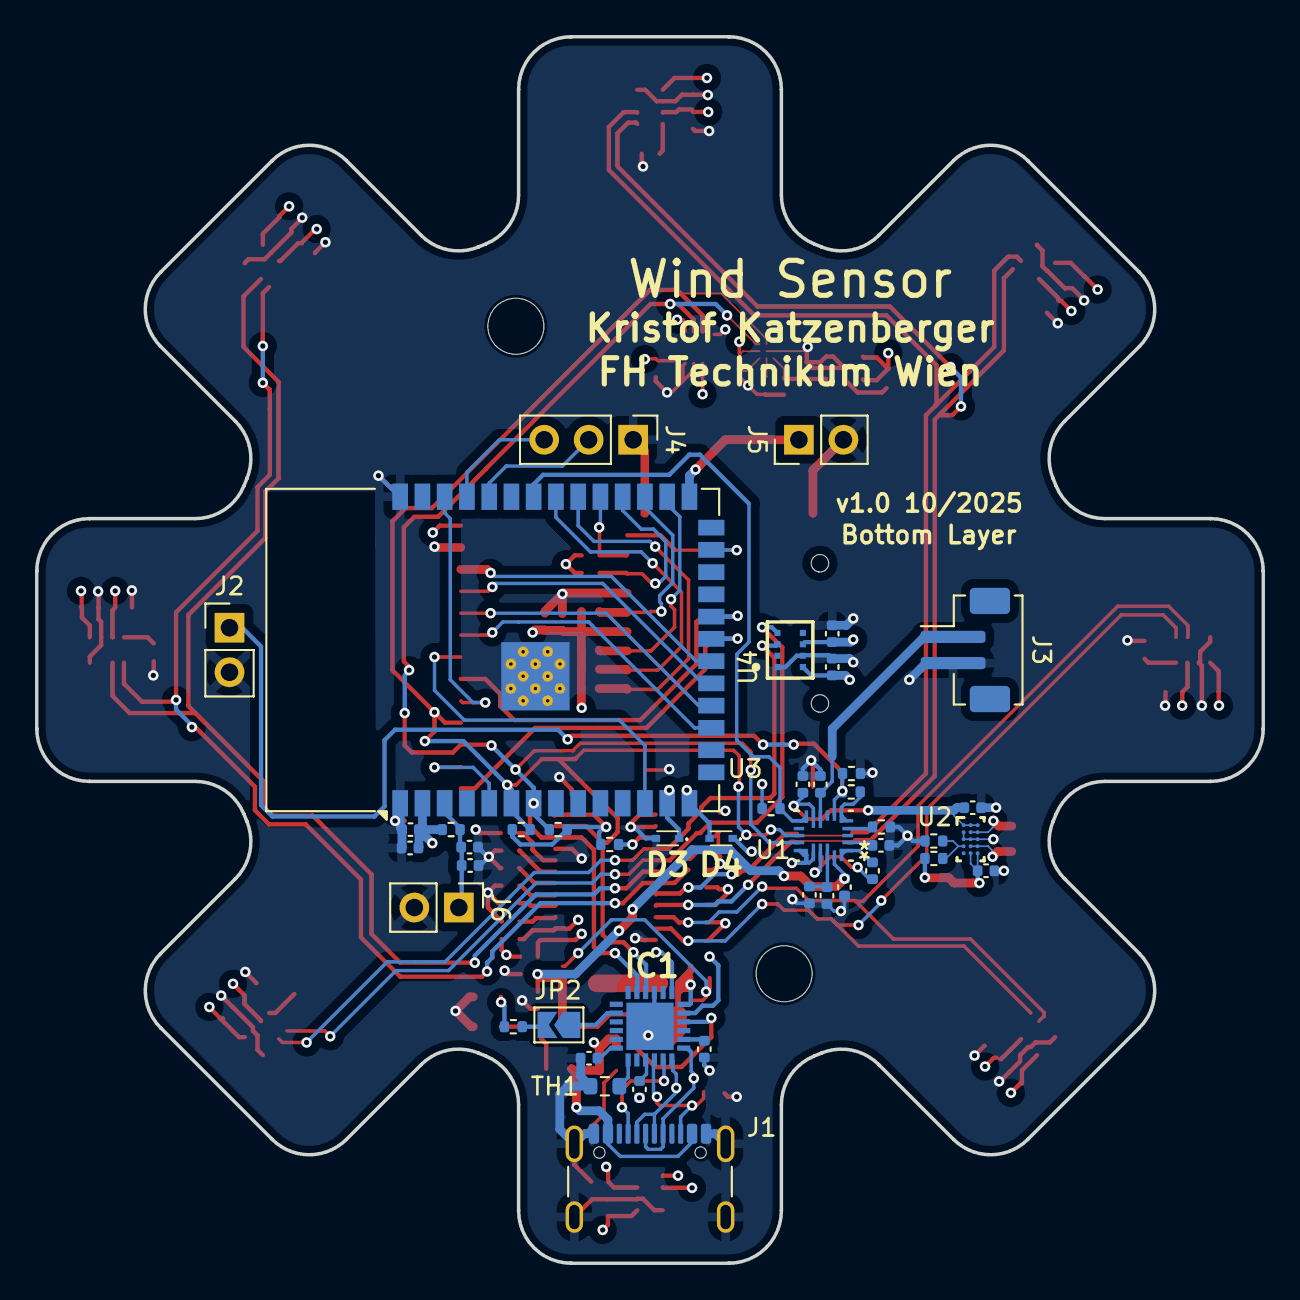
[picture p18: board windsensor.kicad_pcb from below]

Board: 4 copper layers, 70.0 x 70.0 mm, 128 parts (44 on the bottom side), 80 nets.

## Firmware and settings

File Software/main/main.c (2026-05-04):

/*
 * Windsensor Firmware 
 * Author: Kristof Katzenberger
 * File: main.c
 */

#include <stdio.h>
#include <string.h>
#include <math.h>
#include "esp_log.h"
#include "esp_sleep.h"
#include "esp_task_wdt.h"
#include "esp_timer.h"
#include "freertos/FreeRTOS.h"
#include "freertos/semphr.h"
#include "driver/gpio.h"
#include "driver/i2c_master.h"
#include "nvs_flash.h"
#include "nvs.h"

#include "config.h"
#include "sensors.h"
#include "power.h"
#include "display.h"
#include "touch.h"
#include "wifi.h"
#include "sdcard.h"

// Module log tag.
static const char *TAG = "MAIN_APP";

// Shared I2C bus handles.
i2c_master_bus_handle_t main_bus_handle = NULL;
static SemaphoreHandle_t touch_sem = NULL;

// DPS368 sensor instances.
static dps368_t sensors[9];

// Last detected peak pressure.
static int last_max_idx = -1;
static float last_max_pressure = 0.0f;

// Compass calibration and heading filter state.
static float min_x = 10000.0f, max_x = -10000.0f;
static float min_y = 10000.0f, max_y = -10000.0f;
static float min_z = 10000.0f, max_z = -10000.0f;
static bool compass_cal_active = false;
static bool compass_cal_reset = false;
static float last_heading_deg = 0.0f;
static float heading_filter_state_deg = 0.0f;
static bool heading_filter_initialized = false;
static char recording_filename[32] = {0};

static const float compass_heading_filter_alpha = 0.30f;

// Convert pressure difference to estimated wind speed (m/s).
static float pressure_diff_to_wind_ms(float pressure_diff_pa) {
    if (pressure_diff_pa <= 0.0f) {
        return 0.0f;
    }

    return ((pressure_diff_pa * 0.55f) + 10.0f) / 3.6f;
}

// Wrap heading angle into the 0..360 degree range.
static float normalize_heading_deg(float heading_deg) {
    while (heading_deg < 0.0f) {
        heading_deg += 360.0f;
    }
    while (heading_deg >= 360.0f) {
        heading_deg -= 360.0f;
    }
    return heading_deg;
}

// Return shortest signed angular delta between two headings.
static float shortest_heading_delta_deg(float from_deg, float to_deg) {
    float delta = to_deg - from_deg;
    while (delta > 180.0f) {
        delta -= 360.0f;
    }
    while (delta < -180.0f) {
        delta += 360.0f;
    }
    return delta;
}

// Smooth heading with a circular EMA filter.
static float smooth_heading_deg(float raw_heading_deg) {
    raw_heading_deg = normalize_heading_deg(raw_heading_deg);

    if (!heading_filter_initialized || !isfinite(heading_filter_state_deg)) {
        heading_filter_state_deg = raw_heading_deg;
        heading_filter_initialized = true;
        return raw_heading_deg;
    }

    float delta = shortest_heading_delta_deg(heading_filter_state_deg, raw_heading_deg);
    heading_filter_state_deg = normalize_heading_deg(
        heading_filter_state_deg + (compass_heading_filter_alpha * delta)
    );

    return heading_filter_state_deg;
}

// Convert sensor heading into the UI reference frame.
static float heading_to_relative_frame(float sensor_heading_deg) {
    return normalize_heading_deg(sensor_heading_deg + 90.0f);
}

// Prime DPS sensors with a few startup measurement cycles.
static void warmup_dps_measurements(int cycles, TickType_t cycle_delay) {
    if (cycles <= 0) {
        return;
    }

    for (int c = 0; c < cycles; c++) {
        for (int i = 0; i < 9; i++) {
            (void)dps368_measure(&sensors[i]);
        }

        vTaskDelay(cycle_delay);
    }
}

// Check whether verbose debug logs are enabled.
static bool app_debug_logs_enabled(void) {
    return display_get_terminal_output_mode() == TERMINAL_OUTPUT_DEBUG;
}

// Apply per-module log levels for the selected terminal output mode.
static void apply_terminal_output_log_policy(terminal_output_mode_t mode) {
    esp_log_level_t wifi_log_level = (mode == TERMINAL_OUTPUT_DEBUG) ? ESP_LOG_INFO : ESP_LOG_WARN;
    esp_log_level_t peripheral_log_level = (mode == TERMINAL_OUTPUT_DEBUG) ? ESP_LOG_INFO : ESP_LOG_WARN;

    // Reduce Wi-Fi logs outside debug mode.
    esp_log_level_set("wifi", wifi_log_level);
    esp_log_level_set("esp_netif_lwip", wifi_log_level);
    esp_log_level_set("WIFI", wifi_log_level);

    // Reduce infrastructure logs outside debug mode.
    esp_log_level_set("gpio", peripheral_log_level);
    esp_log_level_set("SDCARD", peripheral_log_level);
    esp_log_level_set("sdmmc_common", peripheral_log_level);
    esp_log_level_set("sdmmc_sd", peripheral_log_level);
    esp_log_level_set("vfs_fat_sdmmc", peripheral_log_level);
}

// Map pressure sensor index to relative wind direction angle.
static int wind_direction_deg_from_sensor_idx(int sensor_idx) {
    switch (sensor_idx) {
        case 6: return 0;
        case 5: return 45;
        case 4: return 90;
        case 3: return 135;
        case 2: return 180;
        case 0: return 225;
        case 8: return 270;
        case 7: return 315;
        default: return 0;
    }
}

// Persist compass calibration.
static void save_compass_calibration(void) {
    nvs_handle_t my_handle;
    esp_err_t err = nvs_open("storage", NVS_READWRITE, &my_handle);
    if (err != ESP_OK) return;

    float compass_data[6] = {min_x, max_x, min_y, max_y, min_z, max_z};
    err = nvs_set_blob(my_handle, "compass_cal", compass_data, sizeof(compass_data));
    if (err == ESP_OK) {
        err = nvs_commit(my_handle);
        ESP_LOGI(TAG, "Compass calibration saved");
    }
    nvs_close(my_handle);
}

// Persist pressure calibration.
static void save_pressure_calibration(void) {
    nvs_handle_t my_handle;
    esp_err_t err = nvs_open("storage", NVS_READWRITE, &my_handle);
    if (err != ESP_OK) return;

    float offsets[9];
    for(int i=0; i<9; i++) {
        offsets[i] = sensors[i].offset;
    }

    err = nvs_set_blob(my_handle, "press_offsets", offsets, sizeof(offsets));
    if (err == ESP_OK) {
        err = nvs_commit(my_handle);
        ESP_LOGI(TAG, "Pressure offsets saved");
    }
    nvs_close(my_handle);
}

// Persist wind unit preference.
static void save_wind_unit_setting(void) {
    nvs_handle_t my_handle;
    esp_err_t err = nvs_open("storage", NVS_READWRITE, &my_handle);
    if (err != ESP_OK) return;

    err = nvs_set_u8(my_handle, "wind_unit", (uint8_t)display_get_wind_unit());
    if (err == ESP_OK) {
        err = nvs_commit(my_handle);
        if (err == ESP_OK) {
            ESP_LOGI(TAG, "Wind unit saved");
        }
    }

    nvs_close(my_handle);
}

// Persist terminal output mode preference.
static void save_terminal_output_setting(void) {
    nvs_handle_t my_handle;
    esp_err_t err = nvs_open("storage", NVS_READWRITE, &my_handle);
    if (err != ESP_OK) return;

    err = nvs_set_u8(my_handle, "term_out_mode", (uint8_t)display_get_terminal_output_mode());
    if (err == ESP_OK) {
        err = nvs_commit(my_handle);
        if (err == ESP_OK && app_debug_logs_enabled()) {
            ESP_LOGI(TAG, "Terminal output mode saved");
        }
    }

    nvs_close(my_handle);
}

// Load persisted calibration and settings.
static void load_calibration(void) {
    esp_err_t err = nvs_flash_init();
    if (err == ESP_ERR_NVS_NO_FREE_PAGES || err == ESP_ERR_NVS_NEW_VERSION_FOUND) {
        ESP_ERROR_CHECK(nvs_flash_erase());
        err = nvs_flash_init();
    }
    ESP_ERROR_CHECK(err);

    nvs_handle_t my_handle;
    err = nvs_open("storage", NVS_READWRITE, &my_handle);
    if (err != ESP_OK) {
        ESP_LOGE(TAG, "Error (%s) opening NVS handle!", esp_err_to_name(err));
        return;
    }

    // Load compass calibration (backward compatible format).
    size_t required_size = 0;
    err = nvs_get_blob(my_handle, "compass_cal", NULL, &required_size);
    if (err == ESP_OK && required_size > 0) {
        float *compass_data = malloc(required_size);
        err = nvs_get_blob(my_handle, "compass_cal", compass_data, &required_size);
        if (err == ESP_OK) {
            if (required_size >= sizeof(float) * 4) {
                min_x = compass_data[0]; max_x = compass_data[1];
                min_y = compass_data[2]; max_y = compass_data[3];
            }
            if (required_size >= sizeof(float) * 6) {
                min_z = compass_data[4]; max_z = compass_data[5];
                ESP_LOGI(TAG, "Compass cal loaded (3D): X[%.1f, %.1f] Y[%.1f, %.1f] Z[%.1f, %.1f]", min_x, max_x, min_y, max_y, min_z, max_z);
            } else {
                ESP_LOGI(TAG, "Compass cal loaded (2D - old format)");
            }
        }
        free(compass_data);
    } else {
        ESP_LOGW(TAG, "No compass calibration found");
    }

    // Load pressure offsets.
    required_size = sizeof(float) * 9;
    float offsets[9];
    err = nvs_get_blob(my_handle, "press_offsets", offsets, &required_size);
    if (err == ESP_OK) {
        for(int i=0; i<9; i++) {
            sensors[i].offset = offsets[i];
        }
        ESP_LOGI(TAG, "Pressure offsets loaded");
    } else {
        ESP_LOGW(TAG, "No pressure offsets found");
    }

    uint8_t saved_wind_unit = (uint8_t)WIND_UNIT_PA;
    err = nvs_get_u8(my_handle, "wind_unit", &saved_wind_unit);
    if (err == ESP_OK) {
        display_set_wind_unit((wind_unit_t)saved_wind_unit);
        ESP_LOGI(TAG, "Wind unit loaded: %d", saved_wind_unit);
    } else {
        display_set_wind_unit(WIND_UNIT_PA);
        ESP_LOGW(TAG, "No wind unit setting found");
    }

    uint8_t saved_terminal_output_mode = (uint8_t)TERMINAL_OUTPUT_DEBUG;
    err = nvs_get_u8(my_handle, "term_out_mode", &saved_terminal_output_mode);
    if (err == ESP_OK) {
        display_set_terminal_output_mode((terminal_output_mode_t)saved_terminal_output_mode);
        if (app_debug_logs_enabled()) {
            ESP_LOGI(TAG, "Terminal output mode loaded: %d", saved_terminal_output_mode);
        }
    } else {
        display_set_terminal_output_mode(TERMINAL_OUTPUT_DEBUG);
        ESP_LOGW(TAG, "No terminal output mode setting found");
    }

    nvs_close(my_handle);
}

// Return latest wind snapshot.
void get_wind_data(int *idx, float *diff) {
    *idx = last_max_idx;
    *diff = last_max_pressure;
}

// Return latest compass heading in UI reference frame.
void get_compass_heading_deg(float *heading_deg) {
    if (heading_deg == NULL) {
        return;
    }

    *heading_deg = heading_to_relative_frame(last_heading_deg);
}

static void enter_system_sleep(void);

// Execute action bound to a long press for the current display mode.
static void handle_long_press_action(bool *calibration_done) {
    if (!display_get_power()) {
        display_set_power(true);
        return;
    }

    display_mode_t mode = display_get_mode();

    if (mode == DISPLAY_MODE_SETTINGS) {
        display_enter_settings_menu();
        *calibration_done = false;
    } else if (mode == DISPLAY_MODE_SETTINGS_BACK) {
        display_exit_settings_menu();
    } else if (mode == DISPLAY_MODE_WIND_UNIT) {
        display_cycle_wind_unit();
        save_wind_unit_setting();
    } else if (mode == DISPLAY_MODE_TERMINAL_OUTPUT) {
        display_cycle_terminal_output_mode();
        save_terminal_output_setting();
    } else if (mode == DISPLAY_MODE_CALIBRATION) {
        if (!(*calibration_done)) {
            dps368_calibrate_offsets(sensors, 9);
            save_pressure_calibration();
            display_show_calibration_tick();
            *calibration_done = true;
        }
    } else if (mode == DISPLAY_MODE_COMPASS_CAL) {
        compass_cal_active = !compass_cal_active;
        if (compass_cal_active) {
            compass_cal_reset = true;
            display_show_compass_cal_text("Rotate Compass\nSlowly...");
        } else {
            save_compass_calibration();
            display_show_compass_cal_text("Calibrated!");
        }
    } else if (mode == DISPLAY_MODE_RECORDING) {
        if (sdcard_is_recording()) {
            esp_err_t stop_ret = sdcard_stop_recording();
            if (stop_ret == ESP_OK) {
                recording_filename[0] = '\0';
                display_set_recording_state(false, NULL);
            } else {
                ESP_LOGW(TAG, "Failed to stop recording: %s", esp_err_to_name(stop_ret));
            }
        } else {
            char next_filename[32] = {0};
            esp_err_t start_ret = sdcard_start_recording(next_filename, sizeof(next_filename));

            if (start_ret == ESP_OK) {
                strncpy(recording_filename, next_filename, sizeof(recording_filename) - 1);
                recording_filename[sizeof(recording_filename) - 1] = '\0';
                display_set_recording_state(true, recording_filename);
            } else {
                recording_filename[0] = '\0';
                display_set_recording_state(false, NULL);
                ESP_LOGW(TAG, "Failed to start recording: %s", esp_err_to_name(start_ret));
            }
        }
    } else if (mode == DISPLAY_MODE_POWER) {
        display_set_power(false);
    } else if (mode == DISPLAY_MODE_SLEEP) {
        enter_system_sleep();
    }
}
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
void app_main(void)
{
    // Configure task watchdog.
    esp_task_wdt_config_t twdt_config = {
        .timeout_ms = 60000,
        .idle_core_mask = (1 << portNUM_PROCESSORS) - 1,
        .trigger_panic = true,
    };
    
    if (esp_task_wdt_reconfigure(&twdt_config) != ESP_OK) {
        ESP_ERROR_CHECK(esp_task_wdt_init(&twdt_config));
    }
    
    ESP_ERROR_CHECK(esp_task_wdt_add(NULL));

    ESP_ERROR_CHECK(i2c_master_init());
    
    gpio_set_direction(GPIO_NUM_13, GPIO_MODE_OUTPUT);
    gpio_set_level(GPIO_NUM_13, 1);
    gpio_set_direction(BQ25628_STAT_PIN, GPIO_MODE_INPUT);
    
    vTaskDelay(pdMS_TO_TICKS(100));

    // Start LVGL task on core 1.
    setup_lvgl_display();
    display_set_recording_state(false, NULL);
    xTaskCreatePinnedToCore(lvgl_tick_task, "lvgl", 8192, NULL, 2, NULL, 1);

    // Initialize power and charger control.
    manage_usb_pd();
    vTaskDelay(pdMS_TO_TICKS(200));
    configure_bq25628_init();
    
    // Scan I2C bus for connected devices.
    run_i2c_scan("Main Bus");

    // Initialize touch controller.
    if (touch_init(main_bus_handle) == ESP_OK) {
        ESP_LOGI(TAG, "Touch Driver Initialized");
        
        // Setup touch interrupt task and ISR.
        touch_sem = xSemaphoreCreateBinary();
        xTaskCreate(touch_task, "touch_task", 4096, NULL, 5, NULL); // Priority 5: above main loop.
        
        gpio_install_isr_service(0);
        gpio_isr_handler_add(TOUCH_IRQ_PIN, touch_isr_handler, NULL);
    } else {
        ESP_LOGE(TAG, "Touch Driver Init Failed");
    }

    // Initialize DPS368 driver.
    dps368_init_driver(main_bus_handle);

    // Initialize BMI270 driver.
    static bmi270_sensor_t bmi270;
    if (bmi270_init_driver(main_bus_handle, &bmi270) != ESP_OK) {
        ESP_LOGE(TAG, "BMI270 Init Failed");
    }

    // Initialize BMM350 driver.
    static bmm350_sensor_t bmm350;
    if (bmm350_init_driver(main_bus_handle, &bmm350) != ESP_OK) {
        ESP_LOGE(TAG, "BMM350 Init Failed");
    }

    // Initialize all pressure sensors.
    int sensor_idx = 0;

    // Channels 0-3 each host two sensors (0x76 and 0x77).
    for (int ch = 0; ch < 4; ch++) {
        sensors[sensor_idx].channel = ch;
        sensors[sensor_idx].address = DPS368_ADDR_0;
        if (dps368_init_sensor(&sensors[sensor_idx]) == ESP_OK) {
            ESP_LOGI(TAG, "Sensor %d (Ch %d, 0x76) initialized", sensor_idx, ch);
        } else {
            ESP_LOGE(TAG, "Sensor %d (Ch %d, 0x76) init failed", sensor_idx, ch);
        }
        sensor_idx++;

        sensors[sensor_idx].channel = ch;
        sensors[sensor_idx].address = DPS368_ADDR_1;
        if (dps368_init_sensor(&sensors[sensor_idx]) == ESP_OK) {
            ESP_LOGI(TAG, "Sensor %d (Ch %d, 0x77) initialized", sensor_idx, ch);
        } else {
            ESP_LOGE(TAG, "Sensor %d (Ch %d, 0x77) init failed", sensor_idx, ch);
        }
        sensor_idx++;
    }

    // Channel 4 hosts one sensor (0x77).
    sensors[sensor_idx].channel = 4;
    sensors[sensor_idx].address = DPS368_ADDR_1;
    if (dps368_init_sensor(&sensors[sensor_idx]) == ESP_OK) {
        ESP_LOGI(TAG, "Sensor %d (Ch 4, 0x77) initialized", sensor_idx);
    } else {
        ESP_LOGE(TAG, "Sensor %d (Ch 4, 0x77) init failed", sensor_idx);
    }
    sensor_idx++;

    tca9548_disable_channels();

    load_calibration();

    // Discard first DPS frames to avoid startup outliers.
    warmup_dps_measurements(3, pdMS_TO_TICKS(125));

    apply_terminal_output_log_policy(display_get_terminal_output_mode());

    // Start Wi-Fi services.
    wifi_resume_services();

    ESP_LOGI(TAG, "Ready.");

    TickType_t last_batt_tick = 0;
    TickType_t last_bmi_tick = 0;
    TickType_t last_bmm_tick = 0;
    TickType_t last_dps_tick = xTaskGetTickCount();
    TickType_t last_log_tick = 0;

    const TickType_t batt_period = pdMS_TO_TICKS(1000);
    const TickType_t bmi_period = pdMS_TO_TICKS(200);   // 5 Hz.
    const TickType_t bmm_period = pdMS_TO_TICKS(100);   // 10 Hz compass.
    const TickType_t dps_period = pdMS_TO_TICKS(125);   // 8 Hz.
    const TickType_t log_period = pdMS_TO_TICKS(1000);  // 1 Hz SD logging.
    terminal_output_mode_t last_applied_mode = display_get_terminal_output_mode();
    
    while(1) {
        esp_task_wdt_reset();
        TickType_t now = xTaskGetTickCount();
        terminal_output_mode_t terminal_output_mode = display_get_terminal_output_mode();

        if (terminal_output_mode != last_applied_mode) {
            apply_terminal_output_log_policy(terminal_output_mode);
            last_applied_mode = terminal_output_mode;
        }

        if (now - last_batt_tick >= batt_period) {
            check_battery_status();
            manage_usb_pd();
            last_batt_tick = now;
        }

        if (now - last_bmi_tick >= bmi_period) {
            if (bmi270_read_data(&bmi270) == ESP_OK) {
                if (terminal_output_mode == TERMINAL_OUTPUT_DEBUG) {
                    ESP_LOGI(TAG, "BMI270: Acc[%.2f, %.2f, %.2f] Gyr[%.2f, %.2f, %.2f]",
                             bmi270.sensor_data.acc.x / 16384.0f,
                             bmi270.sensor_data.acc.y / 16384.0f,
                             bmi270.sensor_data.acc.z / 16384.0f,
                             bmi270.sensor_data.gyr.x * 2000.0f / 32768.0f,
                             bmi270.sensor_data.gyr.y * 2000.0f / 32768.0f,
                             bmi270.sensor_data.gyr.z * 2000.0f / 32768.0f);
                } else if (terminal_output_mode == TERMINAL_OUTPUT_RAW_DATA) {
                    printf("Acc: %.2f, %.2f, %.2f | Gyr: %.2f, %.2f, %.2f\n",
                           bmi270.sensor_data.acc.x / 16384.0f,
                           bmi270.sensor_data.acc.y / 16384.0f,
                           bmi270.sensor_data.acc.z / 16384.0f,
                           bmi270.sensor_data.gyr.x * 2000.0f / 32768.0f,
                           bmi270.sensor_data.gyr.y * 2000.0f / 32768.0f,
                           bmi270.sensor_data.gyr.z * 2000.0f / 32768.0f);
                }
            }
            last_bmi_tick = now;
        }

        if (now - last_bmm_tick >= bmm_period) {
            static int bmm350_fail_count = 0;
            if (bmm350_read_data(&bmm350) == ESP_OK) {
                bmm350_fail_count = 0;
                
                if (compass_cal_reset) {
                    min_x = max_x = bmm350.mag_x;
                    min_y = max_y = bmm350.mag_y;
                    min_z = max_z = bmm350.mag_z; // Reset Z-axis calibration bounds.
                    compass_cal_reset = false;
                    heading_filter_initialized = false;
                }

                if (compass_cal_active) {
                    if (bmm350.mag_x < min_x) min_x = bmm350.mag_x;
                    if (bmm350.mag_x > max_x) max_x = bmm350.mag_x;
                    if (bmm350.mag_y < min_y) min_y = bmm350.mag_y;
                    if (bmm350.mag_y > max_y) max_y = bmm350.mag_y;
                    if (bmm350.mag_z < min_z) min_z = bmm350.mag_z; // Update Z-axis calibration bounds.
                    if (bmm350.mag_z > max_z) max_z = bmm350.mag_z; 
                }

                // Compute hard-iron offsets from min/max midpoint per axis.
                float off_x = (min_x + max_x) / 2.0f;
                float off_y = (min_y + max_y) / 2.0f;
                float off_z = (min_z + max_z) / 2.0f; // Z-axis hard-iron offset.
                
                // Apply hard-iron compensation to raw magnetic field.
                float cal_x = bmm350.mag_x - off_x;
                float cal_y = bmm350.mag_y - off_y;
                float cal_z = bmm350.mag_z - off_z;

                // Tilt compensation using an NED frame (X=Forward, Y=Right, Z=Down).
                // Goal: remove roll/pitch influence so heading stays stable while tilted.

                // 1) Map accelerometer data to NED and convert to g-units.
                // These signs follow the validated board orientation.
                float g_x = -(bmi270.sensor_data.acc.y / 16384.0f); // Forward acceleration.
                float g_y = -(bmi270.sensor_data.acc.x / 16384.0f); // Right acceleration.
                float g_z =  (bmi270.sensor_data.acc.z / 16384.0f); // Down acceleration.

                // 2) Map calibrated magnetometer data to the same NED frame.
                // Matching frames is required before any tilt compensation math.
                float m_x = -cal_y; // Forward magnetic component.
                float m_y =  cal_x; // Right magnetic component.
                float m_z =  cal_z; // Down magnetic component.
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

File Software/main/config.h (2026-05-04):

/*
 * Windsensor Firmware 
 * Author: Kristof Katzenberger
 * File: config.h
 */

#ifndef CONFIG_H
#define CONFIG_H

#include "driver/gpio.h"
#include "driver/i2c_master.h"

// --- I2C Configuration ---
#define I2C_MASTER_SCL_IO           GPIO_NUM_7      
#define I2C_MASTER_SDA_IO           GPIO_NUM_6      
#define I2C_MASTER_NUM              I2C_NUM_0        
#define I2C_MASTER_FREQ_HZ          100000           

extern i2c_master_bus_handle_t main_bus_handle;

// --- SD Card (SDMMC 4-bit) ---
#define SD_PIN_CMD                  GPIO_NUM_35
#define SD_PIN_CLK                  GPIO_NUM_36
#define SD_PIN_D0                   GPIO_NUM_37
#define SD_PIN_D1                   GPIO_NUM_38
#define SD_PIN_D2                   GPIO_NUM_39
#define SD_PIN_D3                   GPIO_NUM_40
#define SD_PIN_CD                   GPIO_NUM_NC 

// --- SPI Display Configuration (GC9A01) ---
#define LCD_HOST     SPI2_HOST
#define PIN_NUM_MISO GPIO_NUM_12  
#define PIN_NUM_MOSI GPIO_NUM_11
#define PIN_NUM_CLK  GPIO_NUM_10
#define PIN_NUM_CS   GPIO_NUM_9
#define PIN_NUM_DC   GPIO_NUM_8
#define PIN_NUM_RST  GPIO_NUM_14
#define PIN_NUM_BCKL GPIO_NUM_2

#define LCD_PIXEL_CLOCK_HZ (40 * 1000 * 1000) 
#define LCD_H_RES          240
#define LCD_V_RES          240
#define LCD_CMD_BITS       8
#define LCD_PARAM_BITS     8

// --- Device Addresses ---
#define AP33772S_ADDR               0x52
#define BQ25628_ADDR                0x6A
#define TCA9548_ADDR                0x70 
#define DPS368_0_ADDR               0x76
#define DPS368_1_ADDR               0x77
#define BMM350_ADDR                 0x14
#define BMI270_ADDR                 0x68
#define TOUCH_ADDR                  0x15

// --- Registers & GPIOs ---
// AP33772S Registers (User Provided)
#define AP33772S_REG_STATUS         0x01
#define AP33772S_REG_MASK           0x02
#define AP33772S_REG_OPMODE         0x03
#define AP33772S_REG_CONFIG         0x04
#define AP33772S_REG_PDCONFIG       0x05
#define AP33772S_REG_SYSTEM         0x06
#define AP33772S_REG_VOLTAGE        0x11
#define AP33772S_REG_CURRENT        0x12
#define AP33772S_REG_TEMP           0x13
#define AP33772S_REG_VREQ           0x14
#define AP33772S_REG_IREQ           0x15
#define AP33772S_REG_SRCPDO         0x20 // 26 bytes
#define AP33772S_REG_PD_REQMSG      0x31 // Write Only
#define AP33772S_REG_PD_CMDMSG      0x32 // Write Only
#define AP33772S_REG_PD_MSGRLT      0x33

#define BQ25628_STAT_PIN            GPIO_NUM_41

// BQ25628 Registers (User Provided)
#define BQ25628_REG_ICHG            0x02 // 16-bit
#define BQ25628_REG_VREG            0x04 // 16-bit
#define BQ25628_REG_IINDPM          0x06 // 16-bit
#define BQ25628_REG_VINDPM          0x08 // 16-bit
#define BQ25628_REG_VSYSMIN         0x0E // 16-bit
#define BQ25628_REG_IPRECHG         0x10 // 16-bit
#define BQ25628_REG_ITERM           0x12 // 16-bit

#define BQ25628_REG_CHG_CTRL        0x14
#define BQ25628_REG_CHG_TMR         0x15
#define BQ25628_REG_CHG_CTRL_0      0x16
#define BQ25628_REG_CHG_CTRL_1      0x17
#define BQ25628_REG_CHG_CTRL_2      0x18
#define BQ25628_REG_CHG_CTRL_3      0x19
#define BQ25628_REG_NTC_CTRL_0      0x1A
#define BQ25628_REG_NTC_CTRL_1      0x1B
#define BQ25628_REG_NTC_CTRL_2      0x1C

#define BQ25628_REG_STATUS_0        0x1D
#define BQ25628_REG_STATUS_1        0x1E
#define BQ25628_REG_FAULT_0         0x1F
#define BQ25628_REG_FLAG_0          0x20
#define BQ25628_REG_FLAG_1          0x21
#define BQ25628_REG_FAULT_FLAG_0    0x22

#define BQ25628_REG_ADC_CTRL        0x26
#define BQ25628_REG_ADC_DIS_0       0x27
#define BQ25628_REG_IBUS_ADC        0x28 // 16-bit
#define BQ25628_REG_IBAT_ADC        0x2A // 16-bit
#define BQ25628_REG_VBUS_ADC        0x2C // 16-bit
#define BQ25628_REG_VPMID_ADC       0x2E // 16-bit
#define BQ25628_REG_VBAT_ADC        0x30 // 16-bit
#define BQ25628_REG_VSYS_ADC        0x32 // 16-bit
#define BQ25628_REG_TS_ADC          0x34 // 16-bit
#define BQ25628_REG_TDIE_ADC        0x36 // 16-bit
#define BQ25628_REG_PART_INFO       0x38 

#endif // CONFIG_H

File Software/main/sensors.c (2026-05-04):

/*
 * Windsensor Firmware 
 * Author: Kristof Katzenberger
 * File: sensors.c
 */

#include <stdio.h>
#include <stdlib.h>
#include <string.h>
#include "sensors.h"
#include "config.h"
#include "driver/i2c_master.h"
#include "esp_log.h"
#include "esp_mac.h"
#include "freertos/FreeRTOS.h"
#include "freertos/task.h"
#include "esp_rom_sys.h"

// Global logging tag and handles
static const char *TAG = "SENSORS";
static i2c_master_dev_handle_t tca9548_handle = NULL;
static i2c_master_dev_handle_t dps368_handle_76 = NULL;
static i2c_master_dev_handle_t dps368_handle_77 = NULL;

// DPS368 registers
#define DPS310_REG_PSR_B2       0x00
#define DPS310_REG_PSR_B1       0x01
#define DPS310_REG_PSR_B0       0x02
#define DPS310_REG_TMP_B2       0x03
#define DPS310_REG_TMP_B1       0x04
#define DPS310_REG_TMP_B0       0x05
#define DPS310_REG_PRS_CFG      0x06
#define DPS310_REG_TMP_CFG      0x07
#define DPS310_REG_MEAS_CFG     0x08
#define DPS310_REG_CFG_REG      0x09
#define DPS310_REG_INT_STS      0x0A
#define DPS310_REG_FIFO_STS     0x0B
#define DPS310_REG_RESET        0x0C
#define DPS310_REG_PRODUCT_ID   0x0D
#define DPS310_REG_COEF_START   0x10
#define DPS310_REG_COEF_END     0x21
#define DPS310_REG_COEF_SRCE    0x28

#define DPS310_RESET_CMD        0x09
#define DPS310_MEAS_CTRL_CONT   0x07

// BMI270 helpers

// BMI270 I2C read helper
static int8_t bmi2_i2c_read(uint8_t reg_addr, uint8_t *reg_data, uint32_t len, void *intf_ptr) {
    i2c_master_dev_handle_t handle = (i2c_master_dev_handle_t)intf_ptr;
    esp_err_t ret = i2c_master_transmit_receive(handle, &reg_addr, 1, reg_data, len, 1000);
    return (ret == ESP_OK) ? BMI2_OK : BMI2_E_COM_FAIL;
}

// BMI270 I2C write helper
static int8_t bmi2_i2c_write(uint8_t reg_addr, const uint8_t *reg_data, uint32_t len, void *intf_ptr) {
    i2c_master_dev_handle_t handle = (i2c_master_dev_handle_t)intf_ptr;
    uint8_t *buffer = malloc(len + 1);
    if (!buffer) return BMI2_E_COM_FAIL;
    
    buffer[0] = reg_addr;
    for (uint32_t i = 0; i < len; i++) {
        buffer[i + 1] = reg_data[i];
    }
    
    esp_err_t ret = i2c_master_transmit(handle, buffer, len + 1, 1000);
    free(buffer);
    
    return (ret == ESP_OK) ? BMI2_OK : BMI2_E_COM_FAIL;
}

// BMI270 delay helper
static void bmi2_delay_us(uint32_t period, void *intf_ptr) {
    esp_rom_delay_us(period);
}

// BMI270 driver init
esp_err_t bmi270_init_driver(i2c_master_bus_handle_t bus_handle, bmi270_sensor_t *bmi270) {
    i2c_device_config_t dev_cfg = {
        .dev_addr_length = I2C_ADDR_BIT_LEN_7,
        .device_address = BMI270_ADDR,
        .scl_speed_hz = I2C_MASTER_FREQ_HZ,
    };
    ESP_ERROR_CHECK(i2c_master_bus_add_device(bus_handle, &dev_cfg, &bmi270->i2c_dev_handle));

    bmi270->dev.intf = BMI2_I2C_INTF;
    bmi270->dev.read = bmi2_i2c_read;
    bmi270->dev.write = bmi2_i2c_write;
    bmi270->dev.delay_us = bmi2_delay_us;
    bmi270->dev.intf_ptr = bmi270->i2c_dev_handle;
    bmi270->dev.read_write_len = 32;
    bmi270->dev.config_file_ptr = NULL;

    int8_t rslt = bmi270_init(&bmi270->dev);
    if (rslt != BMI2_OK) {
        ESP_LOGE(TAG, "BMI270 Init failed: %d", rslt);
        return ESP_FAIL;
    }

    // Enable Sensors (Accel + Gyro)
    uint8_t sens_list[2] = {BMI2_ACCEL, BMI2_GYRO};
    rslt = bmi270_sensor_enable(sens_list, 2, &bmi270->dev);
    if (rslt != BMI2_OK) {
        ESP_LOGE(TAG, "BMI270 Enable failed: %d", rslt);
        return ESP_FAIL;
    }

    // Configure Sensors 
    struct bmi2_sens_config config[2];
    config[0].type = BMI2_ACCEL;
    config[0].cfg.acc.bwp = BMI2_ACC_NORMAL_AVG4;
    config[0].cfg.acc.odr = BMI2_ACC_ODR_100HZ;
    config[0].cfg.acc.range = BMI2_ACC_RANGE_2G;
    config[0].cfg.acc.filter_perf = BMI2_PERF_OPT_MODE;

    config[1].type = BMI2_GYRO;
    config[1].cfg.gyr.bwp = BMI2_GYR_NORMAL_MODE;
    config[1].cfg.gyr.odr = BMI2_GYR_ODR_100HZ;
    config[1].cfg.gyr.range = BMI2_GYR_RANGE_2000;
    config[1].cfg.gyr.noise_perf = BMI2_PERF_OPT_MODE;
    config[1].cfg.gyr.filter_perf = BMI2_PERF_OPT_MODE;

    rslt = bmi270_set_sensor_config(config, 2, &bmi270->dev);
    if (rslt != BMI2_OK) {
        ESP_LOGE(TAG, "BMI270 Config failed: %d", rslt);
        return ESP_FAIL;
    }

    ESP_LOGI(TAG, "BMI270 Initialized successfully");
    return ESP_OK;
}

// BMI270 data read
esp_err_t bmi270_read_data(bmi270_sensor_t *bmi270) {
    int8_t rslt = bmi2_get_sensor_data(&bmi270->sensor_data, &bmi270->dev);
    if (rslt != BMI2_OK) {
        ESP_LOGE(TAG, "BMI270 Read failed: %d", rslt);
        return ESP_FAIL;
    }
    return ESP_OK;
}

// TCA9548 handle guard
static esp_err_t ensure_tca9548_handle(void) {
    if (tca9548_handle != NULL) {
        return ESP_OK;
    }
    i2c_device_config_t dev_cfg = {
        .dev_addr_length = I2C_ADDR_BIT_LEN_7,
        .device_address = TCA9548_ADDR,
        .scl_speed_hz = I2C_MASTER_FREQ_HZ,
    };
    return i2c_master_bus_add_device(main_bus_handle, &dev_cfg, &tca9548_handle);
}

// DPS368 driver init
esp_err_t dps368_init_driver(i2c_master_bus_handle_t bus_handle) {
    i2c_device_config_t dev_cfg_76 = {
        .dev_addr_length = I2C_ADDR_BIT_LEN_7,
        .device_address = DPS368_ADDR_0,
        .scl_speed_hz = I2C_MASTER_FREQ_HZ,
    };
    ESP_ERROR_CHECK(i2c_master_bus_add_device(bus_handle, &dev_cfg_76, &dps368_handle_76));

    i2c_device_config_t dev_cfg_77 = {
        .dev_addr_length = I2C_ADDR_BIT_LEN_7,
        .device_address = DPS368_ADDR_1,
        .scl_speed_hz = I2C_MASTER_FREQ_HZ,
    };
    ESP_ERROR_CHECK(i2c_master_bus_add_device(bus_handle, &dev_cfg_77, &dps368_handle_77));
    return ESP_OK;
}

// DPS368 register write helper
static esp_err_t dps368_write_reg(i2c_master_dev_handle_t handle, uint8_t reg, uint8_t val) {
    uint8_t data[2] = {reg, val};
    return i2c_master_transmit(handle, data, 2, 1000);
}

// DPS368 register read helper
static esp_err_t dps368_read_regs(i2c_master_dev_handle_t handle, uint8_t reg, uint8_t *data, size_t len) {
    return i2c_master_transmit_receive(handle, &reg, 1, data, len, 1000);
}
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

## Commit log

2026-05-04 add ECAD files
    [bom.csv, compass.kicad_sch, designators.csv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]
2026-05-04 add MCAD files
    [WindSensor-BatteryHolder.3mf, WindSensor-Bottom.3mf, WindSensor-ScreenConnector.3mf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]
2026-05-04 add Software
    [partitions.csv]
